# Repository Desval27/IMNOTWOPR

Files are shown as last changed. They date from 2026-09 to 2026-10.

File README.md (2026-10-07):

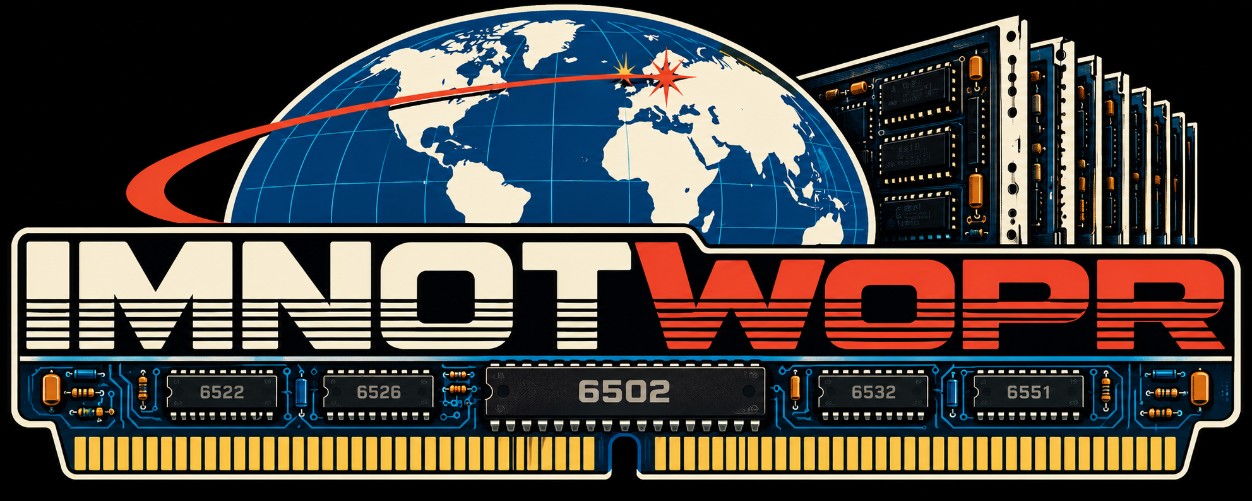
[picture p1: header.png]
Header


# IMNOTWOPR

**IMNOTWOPR** — *Information Management Network Operating Terminal & Wargames Optimized Planning Rig* — is a DIY-friendly, expandable 6502-family computer inspired by the architecture, modularity, and front-panel experience of classic systems such as the IMSAI 8080, while deliberately avoiding strict historical reproduction.

The system combines the open, card-oriented philosophy of S-100 machines with a **3U Eurocard mechanical format and 96-pin DIN 41612 backplane**. The result is intended to be a machine that is visually engaging, electrically accessible, mechanically robust, easy to modify, and suitable for experimenting with hardware, operating systems, peripherals, and alternative CPU configurations.

At its core, IMNOTWOPR is an attempt to build the kind of expandable 6502 computer that might have existed if the modular backplane philosophy of early microcomputers had evolved around the 6502 family instead of the Intel 8080.

## Project Goals

The primary goals of IMNOTWOPR are:

* Build a real, hardware-based 6502-family computer rather than an emulated system.
* Use a passive backplane and independent plug-in cards for CPU, memory, I/O, storage, video, sound, and other functions.
* Preserve the hands-on experience of classic front-panel computers, including blinking status lights, switches, processor control, and direct memory examination.
* Keep the architecture open and experimental rather than enforcing a single fixed memory map or peripheral layout.
* Favor through-hole and DIP components where practical.
* Use modern components where they provide clear benefits without hiding the operation of the machine.
* Make the system easy to probe, understand, modify, repair, and extend.
* Support both the W65C02 and eventual W65C816 CPU cards without redesigning the backplane.
* Provide room for experimenting with custom operating systems, monitors, device drivers, and unconventional hardware.

Historical authenticity is not a primary goal. The machine should feel like a classic expandable microcomputer while benefiting from several decades of hindsight.

## Current Status

All modules and panels are currently a work in progress and **NONE** have been tested yet.

- [Backplane](system/BACKPLANE/README.md)
- [PWR PCB](modules/PWR/README.md)
- [PWR Panel](panels/PWR/README.md)
- [Lightman serial terminal](lightman/README.md) - Pico RGB332 VGA/PS/2 serial terminal with VT100/VT52 firmware and on-device setup, including normal-text color selection.

## Mechanical Architecture

IMNOTWOPR uses the **3U Eurocard format**, with typical cards measuring approximately:

```text
160 mm × 100 mm
```

Cards plug into a passive backplane using **96-pin DIN 41612 connectors**.

This provides several advantages over a traditional PCB-edge S-100 connector:

* standardized card cages and guides,
* robust and replaceable connectors,
* good contact reliability,
* straightforward board insertion and removal,
* readily available mechanical hardware,
* flexible signal and ground assignment,
* and compatibility with existing Eurocard prototyping practices.

The Eurocard format also encourages functional separation. Rather than placing the entire system on one large PCB, the computer can evolve as a collection of specialized cards.

Typical cards may include:

```text
CPU
Memory
System Controller
Serial I/O
VIA / Parallel I/O
Mass Storage
Video
Sound
Networking
RTC
ADC / DAC
Front Panel
Prototype / Experimenter
```

The passive backplane itself should contain as little active circuitry as practical.

## System Bus

[Bus Allocation](doc/bus.md)

The IMNOTWOPR bus is inspired conceptually by S-100, but is designed specifically for the 6502 family.

The initial system is expected to use a **W65C02S**, while the backplane is provisioned from the beginning for eventual use with the **W65C816S**.

The bus therefore provides:

```text
A0-A23       24-bit address bus
D0-D7         8-bit bidirectional data bus

PHI2          System bus clock
R/W           Read/write direction
VALID         Valid external bus cycle
SYNC          Opcode-fetch indication

/RESET
/IRQ
/NMI
RDY

VPB
MLB

VDA
VPA
E
MX
/ABORT
```

Not every CPU implementation is required to generate every signal directly. CPU cards may synthesize bus-level signals so peripheral cards see a consistent interface.

For example, a W65C816 CPU card can latch the processor's multiplexed bank-address byte locally and present normal dedicated `A16-A23` signals to the backplane.

This means ordinary memory and peripheral cards do not need to understand the internal bus peculiarities of the installed processor.

## Address Space

The physical backplane provides a full:

```text
24-bit address bus
```

allowing up to:

```text
16 MiB
```

of physical address space.

A basic W65C02 CPU card operates naturally within bank `$00`:

```text
$000000-$00FFFF
```

with `A16-A23` normally held low.

Future CPU cards may use those lines differently. A W65C816 card can expose its complete 24-bit native address space, while an experimental W65C02 card could implement bank switching or other extended-address mechanisms.

The backplane does **not** enforce a fixed system memory map.

There is no mandatory division between RAM, ROM, and I/O, and no permanently assigned global I/O region. Individual cards may decode whichever portions of the address bus are appropriate.

This allows the machine to support very different system configurations without changing the backplane itself.

## Memory-Mapped I/O

IMNOTWOPR follows the native 6502 model of **memory-mapped I/O**.

Peripheral devices occupy normal addresses within the processor's address space rather than using a separate I/O instruction space.

The bus therefore does not require traditional S-100-style signals such as:

```text
IOR
IOW
INP
OUT
```

A peripheral card generally needs only:

```text
Address
Data
R/W
PHI2
VALID
```

plus any interrupt or DMA-related signals it requires.

This keeps peripheral design closely aligned with normal 6502 conventions.

## Power

Unlike classic S-100 systems, IMNOTWOPR does not distribute unregulated voltages and require every card to contain its own primary regulator.

The backplane distributes regulated power directly:

```text
+5 V      Main digital supply
+12 V     Auxiliary supply
-12 V     Auxiliary supply
GND       Common ground
```

The **+5 V rail** is the primary system supply and is used by normal CPU, memory, and logic cards.

The ±12 V rails are optional auxiliary services intended for devices such as:

* analog circuitry,
* audio interfaces,
* ADC/DAC hardware,
* legacy serial interfaces,
* storage devices,
* experimental peripherals,
* or other hardware requiring additional rails.

A normal digital card should not require ±12 V.

Multiple DIN 41612 contacts are assigned in parallel for +5 V and ground in order to reduce connector resistance and distribute current across the backplane.

Cards may include local filtering, bulk capacitance, protection, and optional secondary regulators as required.

Modern 3.3 V devices should normally derive their supply locally from +5 V rather than making 3.3 V a mandatory system-wide backplane rail.

## Front Panel

A dedicated front-panel controller provides one of the defining features of IMNOTWOPR: a large, interactive display inspired by machines such as the IMSAI 8080.

The panel may include indicators for:

```text
A0-A23
D0-D7
R/W
PHI2
SYNC
IRQ
NMI
RESET
BUS STATE
```

along with physical toggle or push-button controls.

Planned operator functions include:

```text
RUN
STOP
SINGLE CYCLE
SINGLE INSTRUCTION
RESET
EXAMINE
EXAMINE NEXT
DEPOSIT
DEPOSIT NEXT
```

The front panel is not intended merely as decoration. It participates directly in system operation.

### Processor Control

The panel can request that the CPU halt through dedicated control signals.

A processor card handles the details of stopping its particular CPU safely and returns an acknowledgement when it has reached a stable halted state.

This keeps CPU-specific control logic on the CPU card rather than embedding assumptions about a specific processor into the front panel.

### Bus Arbitration

For functions such as `EXAMINE` and `DEPOSIT`, the front-panel controller can temporarily request ownership of the system bus.

The basic handshake is:

```text
/BUS_REQ
/BUS_ACK
```

Once ownership is granted, the CPU card removes its address, data, and control drivers from the bus.

The front-panel controller then becomes a temporary bus master and can perform memory reads and writes directly.

This allows classic front-panel operation without relying on the processor to execute monitor code.

## Clocking

`PHI2` is treated as a **system bus clock**, not merely a private CPU pin.

Halting the processor does not necessarily halt the system clock.

This makes it possible for the front panel and other bus masters to perform valid bus cycles while the processor is stopped.

The initial CPU card may provide the master clock source, although a future dedicated system-controller card could assume that responsibility.

Clock speed is intentionally not fixed by the backplane specification.

The system should be able to operate slowly enough for observation and experimentation while remaining capable of significantly higher speeds when appropriately designed cards are installed.

## Bus Arbitration and Expansion

IMNOTWOPR is designed with the possibility of multiple bus masters.

Potential bus masters may eventually include:

* the CPU,
* front-panel controller,
* DMA controller,
* video hardware,
* storage controller,
* diagnostic hardware,
* or other experimental cards.

A generic request/acknowledge mechanism is preferred over exposing CPU-specific signals directly.

For example:

```text
/BUS_REQ
/BUS_ACK
```

allows a CPU card to translate the generic bus request into whatever mechanism its particular processor requires.

This makes the backplane less dependent upon the details of the W65C02 or W65C816.

## 65C02 and 65C816 Compatibility

The first CPU implementation is expected to use the **W65C02S**.

For that configuration:

```text
A0-A15   CPU address
A16-A23  normally 0
D0-D7    CPU data
```

The backplane nevertheless carries all 24 address bits.

A future **W65C816S** CPU card can use:

```text
A0-A23
D0-D7
```

as a native 24-bit address / 8-bit data architecture.

Any multiplexing required by the processor is handled locally on the CPU card.

The intent is that most RAM, ROM, I/O, and peripheral cards designed for IMNOTWOPR should work with either CPU without modification.

## Component Philosophy

IMNOTWOPR intentionally favors components that remain approachable to hobbyists.

Preferred technologies include:

* W65C02S and W65C816S processors,
* 74HC / 74HCT-series logic,
* DIP SRAM,
* EEPROM or Flash devices,
* W65C22 VIA,
* UARTs and similar peripheral ICs,
* discrete transistors,
* socketed programmable logic where useful,
* and through-hole connectors and passive components.

Surface-mount components are not prohibited, but should not be required merely for convenience if a practical through-hole alternative exists.

Programmable logic such as GALs, CPLDs, or microcontrollers may be used where appropriate, but the core operation of the system should remain understandable without treating large programmable devices as black boxes.

## Open Architecture

One of the fundamental goals of IMNOTWOPR is to avoid defining unnecessary policy at the backplane level.

The system therefore does not require:

* a specific ROM monitor,
* a particular operating system,
* fixed RAM size,
* fixed peripheral addresses,
* a specific storage format,
* a mandatory video system,
* or a single standard machine configuration.

A minimal system might consist of:

```text
CPU
RAM
ROM
Serial I/O
```

while a larger system could contain:

```text
CPU
Multiple RAM cards
ROM / Flash
Serial interfaces
Parallel interfaces
Mass storage
Video
Audio
Networking
Front panel
RTC
ADC / DAC
Custom hardware
```

Both configurations are equally valid.

## Software

Software development is expected to be just as experimental as the hardware.

Possible software projects include:

* machine-language monitors,
* assemblers,
* BASIC interpreters,
* Forth systems,
* custom operating systems,
* multitasking experiments,
* filesystem development,
* device-driver frameworks,
* bootloaders,
* networking stacks,
* 65C816 native-mode software,
* and compatibility environments for existing 6502 software.

No particular software environment is considered canonical.

The machine should be capable of evolving alongside the software written for it.

## Initial Planned Cards

The first generation of the system will likely include some subset of the following:

### CPU Card

W65C02-based processor card providing:

* processor,
* clock generation,
* address and data buffering,
* interrupt handling,
* bus arbitration,
* halt/step support,
* and 24-bit bus adaptation.

### Memory Card

Configurable RAM and ROM/Flash with selectable address decoding.

### Serial Card

Basic terminal interface suitable for initial software development and debugging.

### Front-Panel Controller

Controls system operation and provides address/data/status indicators, processor control, and Examine/Deposit functionality.

### VIA / General I/O Card

One or more W65C22 devices providing:

* digital I/O,
* timers,
* handshake lines,
* interrupts,
* and general experimentation facilities.

### Prototype Card

A general-purpose experimenter board exposing the system bus and providing space for custom circuitry.

Future cards may include storage, video, audio, networking, RTC, ADC/DAC, and other experimental hardware.

## Design Philosophy

IMNOTWOPR is not intended to be the smallest, fastest, cheapest, or most integrated 6502 computer possible.

There are already much easier ways to build those.

Instead, the project deliberately values:

```text
Visibility
Modularity
Experimentation
Repairability
Understandability
Physical controls
Blinking lights
Too many circuit boards
```

over integration.

The machine should invite its owner to remove cards, attach probes, change memory maps, build strange peripherals, write questionable operating systems, single-step instructions from the front panel, and occasionally wonder why there are quite so many LEDs.

That is the point.

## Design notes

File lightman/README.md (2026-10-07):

# lightman

Lightman is a Raspberry Pi Pico (RP2040) serial terminal with RGB332 VGA output,
PS/2 keyboard input, and a DTE male DE-9 RS-232 port through MAX3232 transceivers.

The firmware baseline provides 80x24 text, common VT100/VT52 controls, a US
keyboard layout, buffered UART I/O, an on-device setup menu, and two embedded
fonts. It builds to a Pico UF2. Host tests and cross-compilation are verified;
physical VGA/PS/2/serial operation still needs prototype validation. See the
[compatibility matrix](docs/compatibility.md) for implemented sequences and gaps.

## Build and flash

Dependencies: CMake 3.24+, Python 3, an Arm GNU embedded C/C++ compiler with
C++23 support, and the official Pico SDK (tested: SDK 2.2.0 and GCC 13.2.1).
The SDK builds/downloads `pioasm` and `picotool` if needed. Initialize SDK
submodules for a complete SDK checkout; USB is not used by this firmware.

From the repository root:

```sh
git clone --branch 2.2.0 --depth 1 https://github.com/raspberrypi/pico-sdk.git /path/to/pico-sdk
git -C /path/to/pico-sdk submodule update --init
cmake -S lightman/firmware -B lightman/build/pico \
  -DPICO_SDK_PATH=/path/to/pico-sdk -DCMAKE_BUILD_TYPE=Release
cmake --build lightman/build/pico -j
```

Hold BOOTSEL while connecting the Pico over USB, then copy
`lightman/build/pico/lightman.uf2` to the `RPI-RP2` drive. BOOTSEL flashing works
independently of USB support in the application. UART/USB debug stdio are
both disabled so debug text cannot pollute the serial terminal connection.
The board/layout target is the original 2 MiB Pico, not Pico 2 or Pico W.

## Wiring

| Function | GPIO |
| --- | --- |
| UART TX / RX | 0 / 1 |
| CTS / RTS | 2 / 3 |
| DTR / DSR | 5 / 4 |
| DCD / RI | 6 / 7 |
| PS/2 clock / data | 8 / 9 |
| VGA HSYNC / VSYNC | 13 / 14 |
| VGA R0 / R1 / R2 | 15 / 16 / 17 |
| VGA G0 / G1 / G2 | 18 / 19 / 20 |
| VGA B0 / B1 | 21 / 22 |

See [wiring and electrical interfaces](docs/wiring.md) before connecting the
board. Three MAX3232s support all eight DE-9 signals: TX/RX, RTS/CTS, DTR/DSR,
and DCD/RI, with common ground on pin 5. DSR, DCD and RI are status inputs
displayed in setup; they do not gate serial traffic.
The VGA resistor DACs use channel 0 as the most significant bit; see the wiring
guide for resistor values and signal order.

## Setup

Defaults are **9600 baud, 8N1, no flow control, VT100, local echo off, DEL
Backspace, Regular font, amber normal text**. Press **F12** to open setup.

- Up/Down selects a setting; Left/Right or Space changes it.
- Enter applies settings for this session.
- S applies and saves settings to flash.
- Esc or F12 cancels the draft changes.
- The last menu row restores factory defaults to the draft; apply/save it
  using Enter/S. Terminal mode changes clear the terminal screen.

Choose 300–115200 baud, 7/8 data bits, parity, stop bits, flow control, terminal
mode, echo, Backspace behavior, Regular/Bold font, and **Normal color**:
White, Classic green, Yellow, Amber, Red, Blue, Cyan or Magenta. Color changes
preview immediately in setup; Enter applies, S saves, and Esc/F12 restores the
previous color. Normal color is the base foreground on black; bold, underline,
blink, reverse video and the cursor use the same color. ANSI color SGR remains
unsupported. Amber uses RGB332 levels R=7, G=4, B=0.
The menu shows UART errors, dropped TX/PS/2 data, missed VGA deadlines, and
live DSR, DCD and RI status.
Incoming host text continues updating a separate terminal screen during setup.

Pause the host before changing serial framing or saving. Flash saves briefly
blank VGA and suspend interrupt handling. Two checksummed flash records protect
against an interrupted save; normal UF2 updates preserve saved settings.
Existing saved White/Green/Yellow choices remain valid. Amber is the default
when no valid settings exist or when factory defaults are restored.

## Fonts

Both fonts are compiled into firmware and selected at runtime. Developers can
replace the build-time inputs using `LIGHTMAN_REGULAR_FONT` and
`LIGHTMAN_BOLD_FONT`. See [font assets, format and licensing](assets/fonts/README.md).

## Tests

Portable tests do not require the Pico SDK:

```sh
cmake -S lightman/firmware -B lightman/build/host \
  -DLIGHTMAN_HOST_TESTS=ON -DCMAKE_BUILD_TYPE=Debug
cmake --build lightman/build/host -j
ctest --test-dir lightman/build/host --output-on-failure
```

Tests cover terminal positioning/scrolling/modes/replies, malformed streams,
keyboard sequences, PS/2 frame parity and timeout, settings validation/CRC,
all normal-color presets and their persistence, RGB332 DAC bit mapping,
and generated font data. A seeded 250,000-byte malformed-input exercise checks
cursor bounds. For sanitizer checks add
`-DCMAKE_CXX_FLAGS="-fsanitize=address,undefined -fno-omit-frame-pointer"` to a
separate host build directory. See [hardware acceptance checks](tests/bringup.md)
for the remaining bench work.

## Layout and architecture

- `firmware/src/terminal.cpp`, `keyboard.cpp`, `config.cpp`: portable core.
- `firmware/src/video.cpp`, `video.pio`: PIO/DMA VGA on core 1; core 0 renders
  packed glyph rasters into three buffers and publishes completed frames.
  `firmware/include/colors.h` defines the normal-color palette and DAC encoding.
- `firmware/src/serial.cpp`, `ps2.cpp`: interrupt-driven input; bounded queues.
- `firmware/src/main.cpp`, `settings.cpp`: local setup and flash persistence.
- `firmware/boards/`: pin map; `assets/fonts/`: source fonts and license.
- `tests/`: portable tests and bench procedures; `tools/`: font converter.
- `hardware/`, `mechanical/`: carrier-board and enclosure designs.

Original source is under the repository [MIT license](../LICENSE). Embedded
font assets have their own SIL Open Font License. Dependencies are the official
[Pico SDK](https://github.com/raspberrypi/pico-sdk) and its build tools.

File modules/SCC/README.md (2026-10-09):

# SCC PCB

System Control Card PCB

Status: ⚠Untested⚠

The SCC module provides power control, status indication, and manual bus reset for the IMNOTWOPR computer. It switches the ATX power supply through the backplane power-on signal and uses separate LEDs to indicate standby power and PSU power-good status, automatically extinguishing the standby LED when main power is enabled. The board also provides connections for monitoring the +5 V, +12 V, −12 V, and +12 V2 rails with voltage meters.

Additional info forthcoming.

The SCC module replaces the prior SCC module and corrects some of its defects.

## Documents

- [Schematic](SCC_schematic.pdf)
- [Assembly](SCC_assembly.pdf)
- [Bill of Materials](bom.csv)
- [Interactive Bill of Materials](ibom.html)

## Gerber To Order

- [Default](gerber_to_order/SCC_160.0x100.0mm_for_Default.zip)
- [Elecrow](gerber_to_order/SCC_160.0x100.0mm_for_Elecrow.zip)
- [FusionPCB](gerber_to_order/SCC_160.0x100.0mm_for_FusionPCB.zip)
- [JLCPCB](gerber_to_order/SCC_160.0x100.0mm_for_JLCPCB.zip)
- [PCBWay](gerber_to_order/SCC_160.0x100.0mm_for_PCBWay.zip)

## Rendered Images

### Top 3D

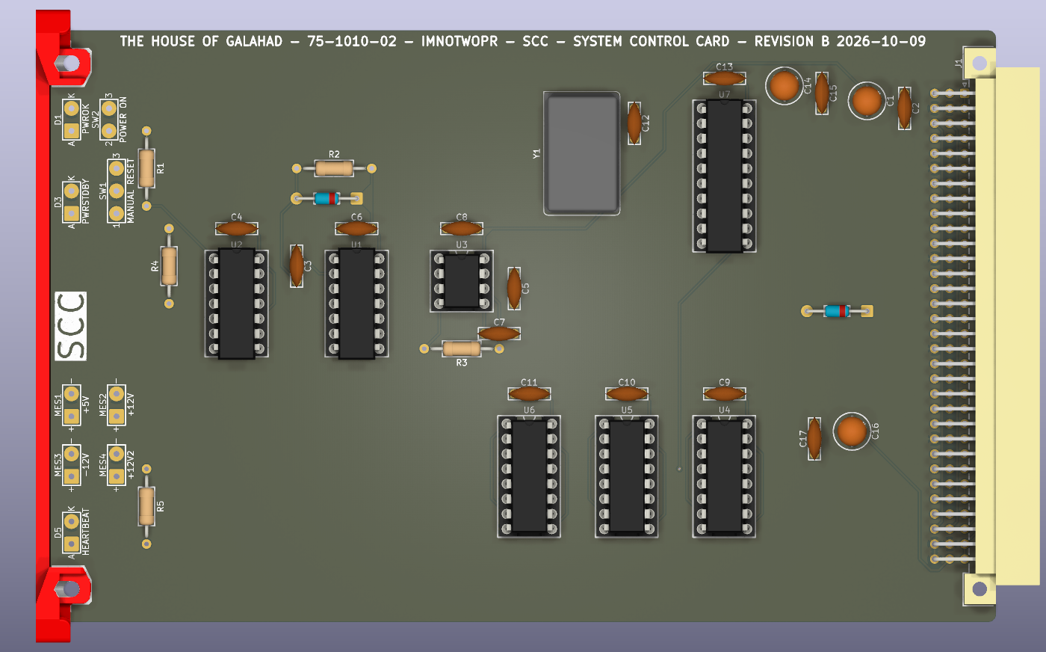
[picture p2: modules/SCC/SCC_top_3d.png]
PCB Top 3D Render


### Top

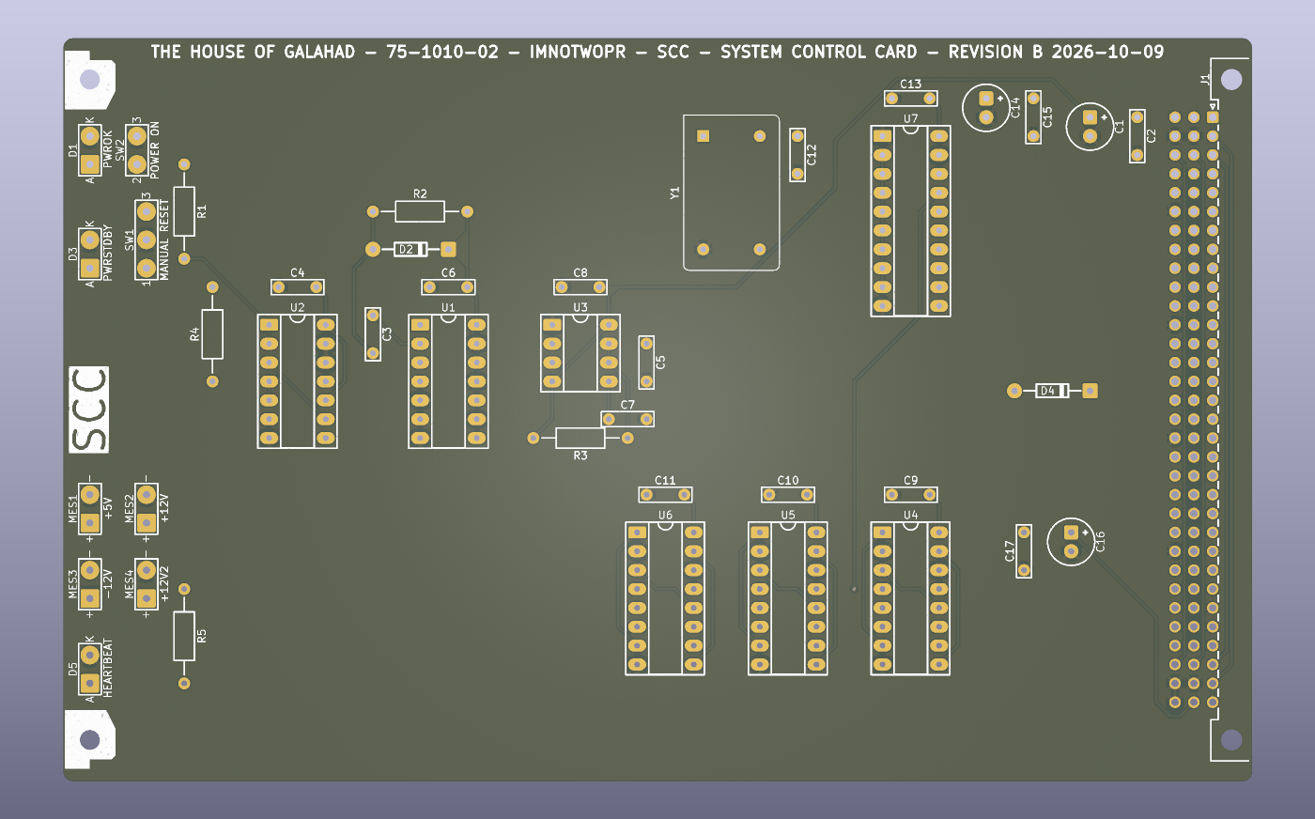
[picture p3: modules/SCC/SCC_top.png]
PCB Top Render


### Bottom

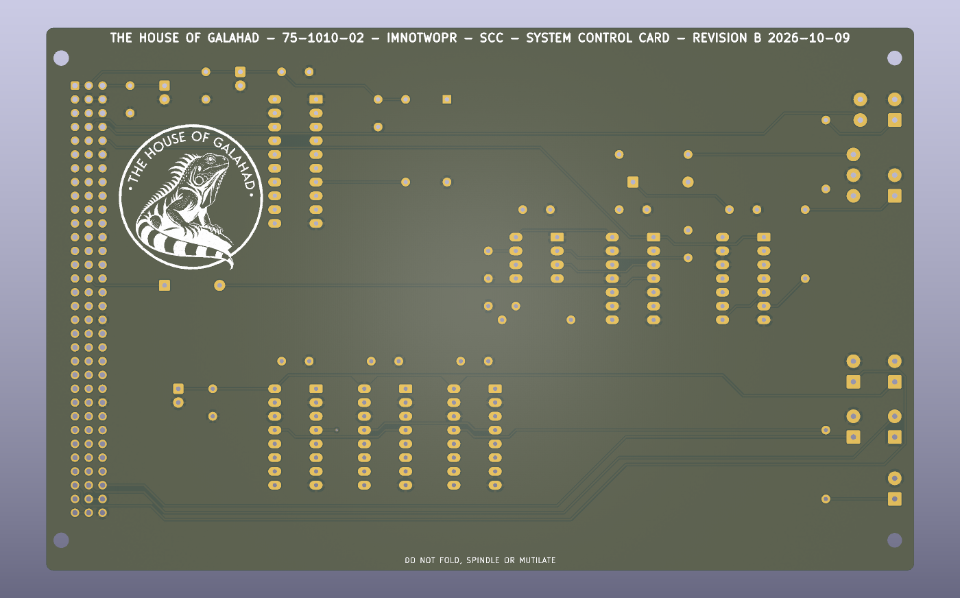
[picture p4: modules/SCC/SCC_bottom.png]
PCB Bottom Render


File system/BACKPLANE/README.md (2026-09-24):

# BACKPLANE

System Bus

Status: Untested

The BACKPLANE PCB provides the shared bus and power distribution for the IMNOTWOPR modular computer, connecting CPU, memory, I/O, and front-panel cards through 20 96-pin DIN 41612 slots. It carries the 24-bit address bus, 8-bit data bus, clock and control signals, and auxiliary I²C and SPI interfaces. ATX power connectors supply the system power rails, with standby power and power-control signals available to the cards. The passive design also includes jumper-selectable I²C pull-ups.

The PWR module and the BACKPLANE both provide the option for I²C pull-ups for convenience.  Only on should be enabled at a time.

## Documents

- [Schematic](BACKPLANE_schematic.pdf)
- [Assembly](BACKPLANE_assembly.pdf)
- [Bill of Materials](bom.csv)
- [Interactive Bill of Materials](ibom.html)

## Gerber To Order

- [Default](gerber_to_order/BACKPLANE_425.28x128.7mm_for_Default.zip)
- [Elecrow](gerber_to_order/BACKPLANE_425.28x128.7mm_for_Elecrow.zip)
- [FusionPCB](gerber_to_order/BACKPLANE_425.28x128.7mm_for_FusionPCB.zip)
- [JLCPCB](gerber_to_order/BACKPLANE_425.28x128.7mm_for_JLCPCB.zip)
- [PCBWay](gerber_to_order/BACKPLANE_425.28x128.7mm_for_PCBWay.zip)

## Rendered Images

### Top 3D

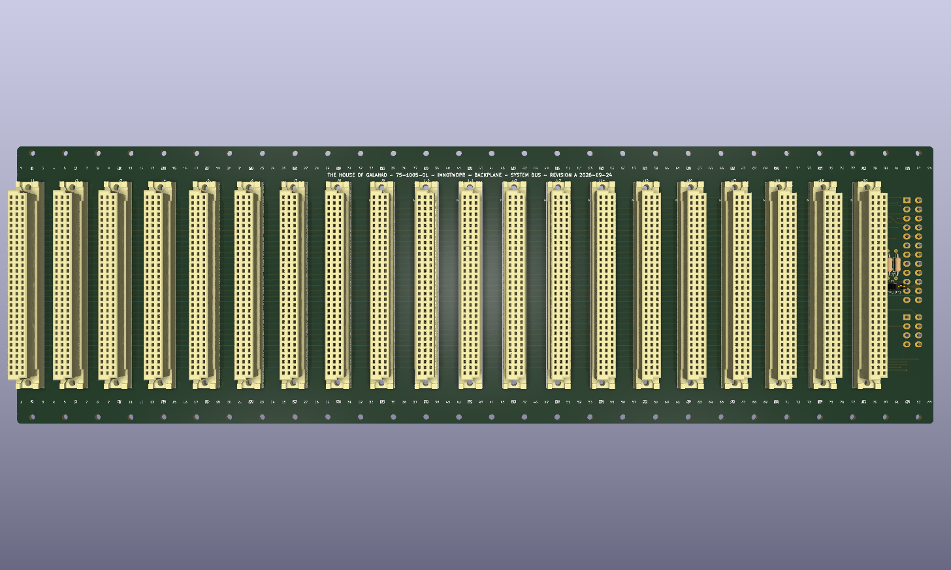
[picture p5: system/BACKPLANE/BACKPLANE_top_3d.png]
PCB Top 3D Render
 3D

### Top

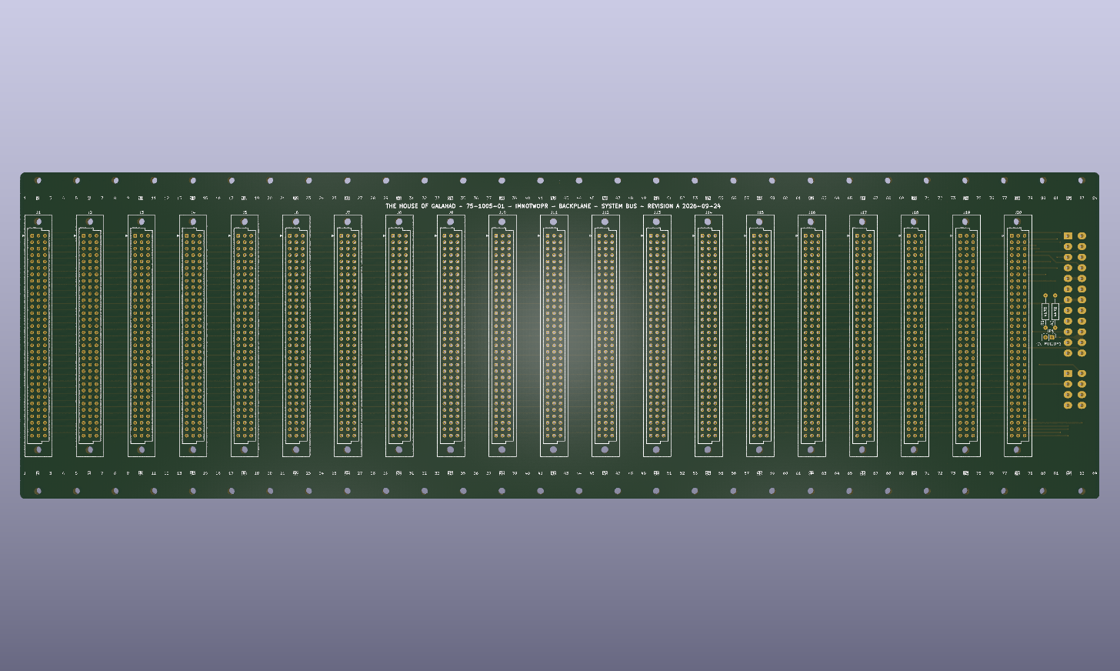
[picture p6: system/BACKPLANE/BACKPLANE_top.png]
PCB Top Render


### Bottom

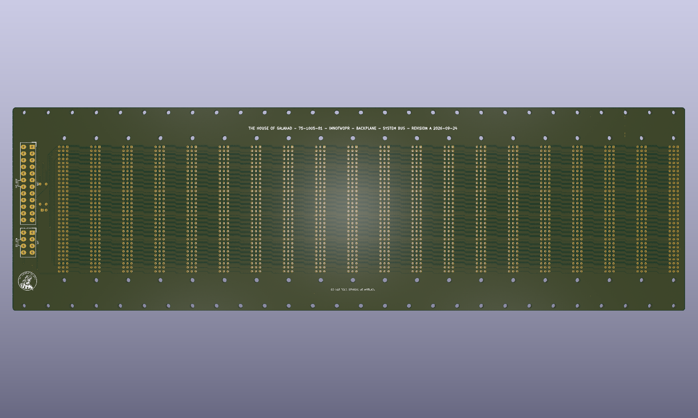
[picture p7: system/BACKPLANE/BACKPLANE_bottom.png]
PCB Bottom Render


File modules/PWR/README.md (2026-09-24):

# PWR PCB

Power Control Module PCB

Status: Untested

The PWR module provides power control, status indication, and manual bus reset for the IMNOTWOPR computer. It switches the ATX power supply through the backplane power-on signal and uses separate LEDs to indicate standby power and PSU power-good status, automatically extinguishing the standby LED when main power is enabled. The board also provides connections for monitoring the +5 V, +12 V, −12 V, and +12 V2 rails with voltage meters, along with jumper-selectable I²C pull-ups.

The PWR module and the BACKPLANE both provide the option for I²C pull-ups for convenience.  Only on should be enabled at a time.

## Documents

- [Schematic](PWR_schematic.pdf)
- [Assembly](PWR_assembly.pdf)
- [Bill of Materials](bom.csv)
- [Interactive Bill of Materials](ibom.html)

## Gerber To Order

- [Default](gerber_to_order/PWR_160.0x100.0mm_for_Default.zip)
- [Elecrow](gerber_to_order/PWR_160.0x100.0mm_for_Elecrow.zip)
- [FusionPCB](gerber_to_order/PWR_160.0x100.0mm_for_FusionPCB.zip)
- [JLCPCB](gerber_to_order/PWR_160.0x100.0mm_for_JLCPCB.zip)
- [PCBWay](gerber_to_order/PWR_160.0x100.0mm_for_PCBWay.zip)

## Rendered Images

### Top 3D

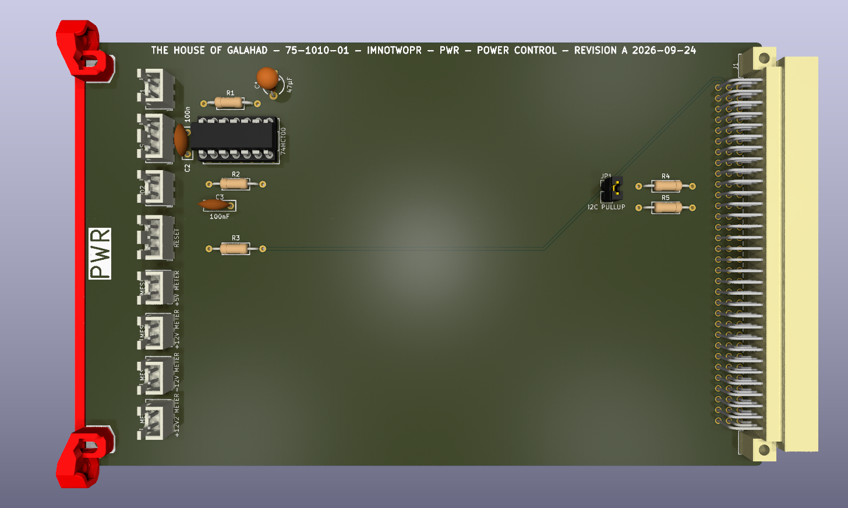
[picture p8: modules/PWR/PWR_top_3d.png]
PCB Top 3D Render


### Top

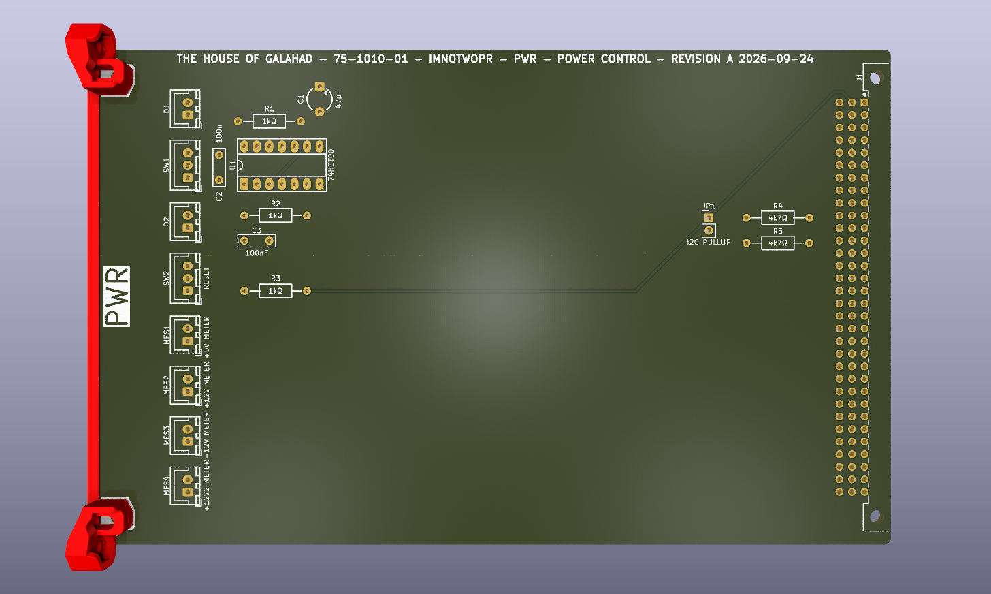
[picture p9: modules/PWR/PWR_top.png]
PCB Top Render


### Bottom

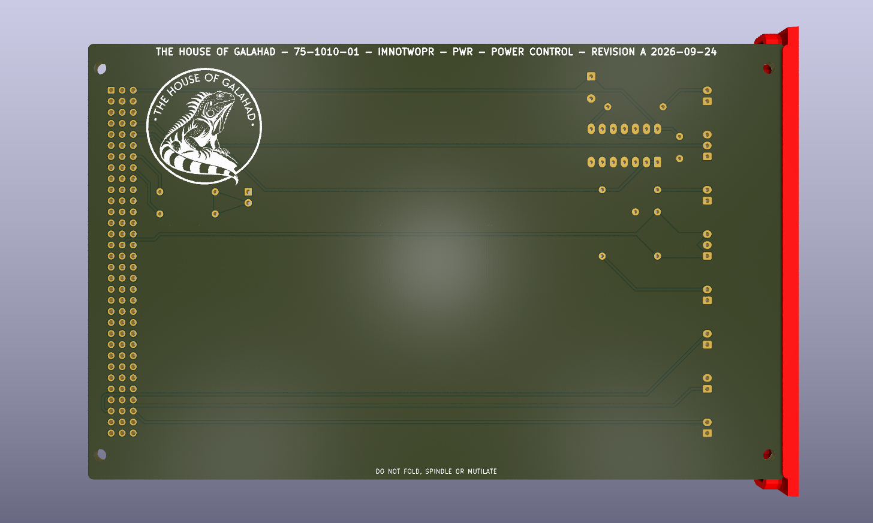
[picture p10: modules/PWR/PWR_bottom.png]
PCB Bottom Render


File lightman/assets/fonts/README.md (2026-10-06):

# Embedded fonts

`lightman-regular.psf` and `lightman-bold.psf` are 8x16 Unicode-mapped PSF inputs
obtained from Debian/Ubuntu `console-setup-linux`'s `Lat15-Terminus16.psf.gz`
and `Lat15-TerminusBold16.psf.gz`. They derive from **Terminus Font**, copyright
(c) 2010 Dimitar Toshkov Zhekov. See [OFL.txt](OFL.txt) for the complete SIL Open
Font License 1.1 and reserved-name notice. Lightman's converted/embedded
derivatives are named Lightman Regular and Lightman Bold.

The build embeds ASCII 32–126, with blank control characters. Firmware supplies
DEC drawing glyphs separately. Font rows use the high bit as the left pixel.
These font assets remain under the OFL; the rest of Lightman's original source
uses the repository MIT license.

The fixed runtime set consists of Regular and Bold. Setup selects the base
font; SGR bold always chooses the Bold slot. Developers can replace either at
build time:

```sh
cmake -S lightman/firmware -B lightman/build/pico \
  -DPICO_SDK_PATH=/path/to/pico-sdk \
  -DLIGHTMAN_REGULAR_FONT=/absolute/path/regular.psf \
  -DLIGHTMAN_BOLD_FONT=/absolute/path/bold.psf
cmake --build lightman/build/pico -j
```

Inputs must be uncompressed PSF1 or PSF2, 8x16, with a Unicode mapping covering
printable ASCII. The converter rejects incompatible or truncated files. Font
changes automatically regenerate `fonts.h`; Python is a build dependency only.
Preserve the license/attribution of any replacement fonts. Font dimensions and
slot count are fixed in this baseline; adding different cell sizes requires
corresponding renderer, layout, configuration and tests changes.

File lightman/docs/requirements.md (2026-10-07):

# Lightman baseline requirements

The initial firmware targets the original Raspberry Pi Pico (RP2040, 2 MiB
flash). See [platform](platform.md), [wiring](wiring.md), and
[compatibility](compatibility.md) for implementation details.

| Area | Selected baseline |
| --- | --- |
| Display | Fixed 640x480 at 60 Hz; 80x24 text centered vertically |
| VGA pins | HSYNC 13, VSYNC 14, R0..R2 15..17, G0..G2 18..20, B0..B1 21..22 |
| Color | RGB332 resistor DACs; channel 0 is most significant; amber normal text by default |
| Keyboard | PS/2 set 2 through level shifters; US layout; clock GPIO8, data GPIO9 |
| Serial | UART0 on GPIO0/1; three MAX3232s support all DTE male DE-9 signals |
| Optional handshaking | CTS/RTS on GPIO2/3, DTR/DSR on GPIO5/4 |
| Modem status | DSR on GPIO4, DCD on GPIO6, RI on GPIO7; live status in setup |
| Framing | 300–115200 baud, 7/8 bits, N/E/O parity, 1/2 stop bits |
| Flow | None, XON/XOFF or RTS/CTS; bounded RX/TX queues |
| Emulation | Documented VT100/VT52 subset, ASCII and DEC drawing characters |
| Setup | F12 local menu, session apply or persistent save; eight normal-color presets including Classic green, Amber and White |
| Fonts | Fixed Regular/Bold set; developer-replaceable 8x16 PSF inputs |
| Persistence | Two versioned CRC32 records in the last two flash sectors |
| Build | C++23, CMake, Pico C SDK; portable host tests |

US layout and DTE wiring were confirmed for this baseline. USB keyboard input,
modem management, and complete DEC conformance remain outside the current
implementation. Power, enclosure, connector footprints and PCB routing still
require hardware validation against the updated pin map.

Before declaring hardware support validated, complete the
[bring-up procedure](../tests/bringup.md), including VGA deadline monitoring
under sustained serial/keyboard load and settings-save recovery.

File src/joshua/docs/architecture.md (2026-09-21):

# Architecture and initial specification

Joshua is the hosted development companion to IMNOTWOPR. The hardware repository
intentionally does not define a mandatory memory map; Joshua follows that rule.
The initial processor has a 16-bit address space. Future 65816/banked systems are
not implied by the first implementation.

## Ownership

```mermaid
flowchart TD
    App[Console application] --> Monitor
    App --> Machine
    Monitor --> Machine
    Machine --> CPU[W65C02 CPU]
    Machine --> Bus[Memory map and bus clock]
    CPU --> Bus
    Bus --> RAM
    Bus --> ROM
    Bus --> VIA[W65C22 VIA]
    Bus --> ACIA[W65C51N ACIA]
    App --> Terminal[POSIX or Windows terminal]
    Terminal --> ACIA
```

`Machine` composes the CPU, bus, device instances and execution breakpoints. The
CPU depends only on `Bus`, not the console, monitor, profile format or a particular
memory map. `Device` defines read, write, peek, reset, tick and IRQ behavior. A
RAM/ROM device is storage with a protection policy. The bus decoder has no built-in
IMNOTWOPR addresses. Mappings are immutable after machine construction in 0.1.

The public headers are under `include/joshua`; implementation is under `lib`.
`app/terminal.cpp` contains the platform-specific APIs. The core uses standard
C++23 and can be embedded in a different host application without console code.
No network service, compiler, external assembler or third-party CPU library runs
inside Joshua.

## Execution and time

`Cpu::step()` completes one instruction or interrupt entry. Each CPU read/write
calls the bus; the bus performs the access, advances one cycle, ticks every mapped
device, and optionally emits a `BusCycle` record. Dummy reads are real bus reads,
including their device side effects. Read-modify-write instructions use the CMOS
two-read/one-write sequence. Device time is never advanced in a lump after an
instruction.

Bus time is a monotonically increasing 64-bit cycle count. Reset takes seven bus
cycles and retains the elapsed counter. Power-on gives deterministic initial
register values; software must still initialize registers as it would on hardware.
Reset adjusts SP by three, sets I and clears D, and loads the reset vector.

The public stepping boundary is an instruction, not an individual PHI2 edge.
WAI advances peripherals while the CPU is waiting; STP stops CPU execution until
reset. IRQ is the logical OR of the mapped devices' IRQ state; NMI is explicitly
latched. The current interrupt decision is made at instruction boundaries.
This does not yet reproduce all interrupt sampling windows or external pin edges.

The host run loop handles terminal input, drains completed serial bytes, evaluates
execution breakpoints and optionally paces execution against `steady_clock`.
Host sleeps do not advance emulated time. Input is polled in bounded batches so a
large paste cannot starve execution. There is no background emulation thread;
paused inspection does not race CPU execution.

## Debugger semantics

`Bus::peek()` is a side-effect-free device view. `Bus::patch()` validates all
addresses before modifying RAM/ROM and does not tick devices. The monitor's load,
deposit and assembler use this path; save and disassembly use peek. Explicit
`io` commands use the normal read/write path. No implicit device write happens
when opening a memory view.

Instruction decoding, disassembly and ad-hoc assembly share one opcode table.
Breakpoints are host metadata, never BRK patches in the guest image. There are no
symbol files, read/write watchpoints, conditional breakpoints or snapshot files in
0.1; raw binary load/save operates only on memory bytes.

## Configuration decisions

- Initial machine: W65C02, VIA at `$8000`, ACIA at `$8010`, 32 KiB RAM and 16 KiB ROM.
- W65C51 means the current W65C51N behavior, including its transmit-empty quirk.
- CPU clock: 1 MHz by default. ACIA reference: 1.8432 MHz; default asserted DCD,
  DSR and CTS inputs represent a connected terminal.
- Input control: Ctrl-] enters the monitor. `run` resumes. The profile/CLI can
  change the escape byte; `send` can inject that byte into the guest.
- Config files use a strict, small `key = value` grammar and no dependency on
  TOML/JSON libraries. Unknown options and invalid maps fail before execution.
- Default number notation is monitor-style hexadecimal. Base prefixes are explicit.
- Unmapped reads return `$FF`; unmapped and ROM CPU writes are ignored.
- Map aliases, overlapping decode/bank switching and multiple VIA/ACIA instances
  are future extensions. Multiple distinct RAM and ROM regions already work.

## Next accuracy work

The immediate hardware work is to validate peripheral timing and interrupt entry
against captures from the actual IMNOTWOPR parts. VIA shift modes, port latching,
and CA/CB handshakes need a pin model. UART echo, break and modem-line transitions
need an explicit serial-line model. Unsupported configuration modes currently
raise an error so they cannot silently appear to work.

After that, introduce externally driven RDY/reset/NMI/IRQ lines and a resumable
single-cycle CPU interface for front-panel or bus-arbitration work. Keep these
changes below `Machine`; neither the monitor nor terminal should determine
processor timing.

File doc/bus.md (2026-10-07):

# IMNOTWOPR BUS ASSIGNMENT #

The system bus uses a **96-pin DIN 41612 connector** which is broken out into three different rows.

| PIN  | a | b | c |
| :----: | :---: | :---: | :---: |
| 1 | +5V | +5V | +5VSB |
| 2 | +5V | GND | GND |
| 3 | +12V | -12V | +12V2 |
| 4 | A0 | #VALID | #PSON |
| 5 | A1 | PHI2 | PWROK |
| 6 | A2 | #RW | GND |
| 7 | A3 | #RESET | I2C_SCL  |
| 8 | A4 | #IRQ | I2C_SDA  |
| 9 | A5 | #NMI | SPI_SCK  |
| 10 | A6 | READY | SPI_MOSI |
| 11 | A7 | BE | SPI_MISO |
| 12 | A8 | SYNC | GND |
| 13 | A9 | VPB | SPI_ID0  |
| 14 | A10 | MLB | SPI_ID1  |
| 15 | A11 | VDA | SPI_ID2  | 
| 16 | A12 | VPA | SPI_ID3  |
| 17 | A13 | E | #SPI_SEL |
| 18 | A14 | MX | GND |
| 19 | A15 | RESERVED  | #SERIRQ  |
| 20 | A16 | RESERVED  | #BUSREQ0 |
| 21 | A17 | RESERVED  | #BUSGNT0 |
| 22 | A18 | D0 | #BUSREQ1 |
| 23 | A19 | D1 | #BUSGNT1 |
| 24 | A20 | D2 | GND |
| 25 | A21 | D3 | #BUSREQ2 |
| 26 | A22 | D4 | #BUSGNT2 |
| 27 | A23 | D5 | #BUSREQ3 |
| 28 | RESERVED | D6 | #BUSGNT3 |
| 29 | RESERVED | D7 | RESERVED |
| 30 | +12V | -12V | +12V2 |
| 31 | +5V | GND | GND |
| 32 | +5V | +5V | GND |

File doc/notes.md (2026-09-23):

# Mechanical Design Notes

These notes define the revised PCB, front-panel, and backplane specifications, using 4 HP (20.32 mm) card spacing. The KiCad layouts are pending updates to match this specification; see [Layout Updates Pending](#layout-updates-pending).

## PCB and Front-Panel Specifications

The mechanical design uses a simplified interpretation of IEC 60297-3-101. The original reference is this [system explanation](https://www.scribd.com/document/53335543/IEC-60297-3-101-system-explanation), rather than the standard itself. The closest configuration is an unshielded plug-in unit with static cantilever handles. Handle mounting holes are omitted for appearance but can be added if needed.

- **Card cage:** SCHROFF [24564-131](https://www.nvent.com/en-us/schroff/products/enc24564-131), a 3U, 84 HP, 175 mm-deep subrack for 160 mm cards, with rear L-ST rails, threaded inserts, and insulation strips.
- **Card size:** Single-height Eurocards, 160 mm deep by 100 mm high, for use in a 3U subrack.
- **PCB thickness:** 1.6 mm.
- **PCB brackets:** nVent SCHROFF [60807-011](https://www.nvent.com/en-us/schroff/products/enc60807-011) brackets attach the PCBs to the front panels using M2.5 hardware. Other brackets may work but have not been tested for this project.
- **Front-panel height:** 128.4 mm, sized for a 3U subrack.
- **Front-panel width:** The intended design uses multiples of 4 HP, where 1 HP = 5.08 mm (0.200 in). Physical panels are slightly narrower than their nominal HP allocation to provide clearance.

Typical panel widths are listed below. The physical widths match the [SCHROFF front-panel catalog](https://www.nvent.com/sites/default/files/acquiadam_assets/2023-04/7_1_schroff_cat_frontpanels_en.pdf).

| Nominal width | Allocated width | Physical panel width |
| --- | --- | --- |
| 4 HP | 20.32 mm | 20.0 mm |
| 8 HP | 40.64 mm | 40.3 mm |
| 12 HP | 60.96 mm | 60.6 mm |
| 16 HP | 81.28 mm | 80.9 mm |

Other panel widths are possible, provided they accommodate the card spacing and components. To fill an 84 HP subrack, the nominal widths of all panels, including any blanking panels, must total 84 HP.

### Bracket Mounting Holes

- **On the front panel:** Both hole centers lie 7.45 mm from the left edge, viewed from the front. The lower hole is 14.7 mm above the bottom edge. The upper hole is 99 mm above the lower hole, placing it 14.7 mm below the top edge.
- **On the PCB:** The intended hole diameter is 2.7 mm for M2.5 hardware. Both centers are specified as 3.56 mm from the front edge of the card (the left edge in the PCB template). The holes are 88.9 mm apart vertically and centered within the board's 100 mm height, leaving 5.55 mm from each hole center to the nearest top or bottom edge.

## Backplane Specifications

The backplane spans 84 HP and provides 21 connector positions at 4 HP (20.32 mm) spacing. Reserving the rightmost 4 HP position for power management leaves 20 positions for other cards. Wider cards may occupy more than one position.

The dimensions below define the revised backplane geometry, viewed from the connector side. Horizontal connector locations use the first slot pitch reference plane, not the cut PCB edge. Vertical offsets use the bottom PCB edge. Hole locations refer to their centers.

### Board Outline and Mounting Holes

| Feature | Revised dimension or location |
| --- | --- |
| Nominal 84 HP allocation | 426.72 mm (16.800 in); not the physical PCB width |
| Physical board width | 425.28 mm design target, centered on the 84 HP mounting grid |
| Board height | 128.70 mm (5.067 in) |
| Bottom mounting-hole row | 3.10 mm above the bottom edge, with the rows centered vertically |
| Top mounting-hole row | 125.60 mm above the bottom edge, with the rows centered vertically |
| Vertical mounting-hole pitch | 122.50 mm |
| Leftmost mounting-hole column | 6.90 mm from the left PCB edge; second rail-grid hole from the left |
| Rightmost mounting-hole column | 418.38 mm from the left PCB edge (6.90 mm from the right); second rail-grid hole from the right |

The centered-row calculation is (128.70 - 122.50) / 2 = 3.10 mm. The former 120.00 mm pitch and 4.35 mm edge margins are superseded. Intermediate mounting-hole columns are not specified here.

On the project's SCHROFF card cages, the outermost rail holes at both sides secure the side panels and are unavailable for backplane mounting. Use the next hole inward at each end, a 1 HP (5.08 mm) shift. Confirm screw-head and washer clearance at these positions.

The [SCHROFF EuropacPRO catalog, pages 6.8, 6.32, and 6.35](https://may-static.de/cms/content%20links/baugruppentraeger/td_227.en.pdf) identifies the kit's rear rails and shows the 84 HP insulation strip's end-hole span as 83 x 5.08 = 421.64 mm. With the PCB centered on that grid, the occupied end holes lie (425.28 - 421.64) / 2 = 1.82 mm from each PCB side. Moving one hole inward gives 1.82 + 5.08 = 6.90 mm. These are calculated coordinates for the chosen centered outline, not dimensions quoted from a kit-specific PCB drawing.

The four outer backplane mounting-hole centers are therefore (6.90, 3.10), (6.90, 125.60), (418.38, 3.10), and (418.38, 125.60) mm, measured from the PCB's lower-left corner on the connector side. Their horizontal separation is 411.48 mm. The former 2.54 mm PCB-edge offsets are superseded.

Published references:

- [SCHROFF Design Guide, page 11, Figure 6](https://www.digikey.sg/Site/Global/Layouts/DownloadPdf.ashx?pdfUrl=044BECE460B74307A75CB81661D5BB75): 122.50 mm mounting pitch and connector offsets from pitch references. Its example board height is 128.55 mm.
- [SCHROFF VME/VME64x manual, page 15](https://www.nvent.com/sites/default/files/acquiadam_assets/2021-06/73972-103.pdf): 128.70 mm height for a 3U VME backplane. Thus 128.70 mm is a published implementation size, not the only possible 3U outline.
- [SCHROFF VME assembly drawing, page 2](https://www.nvent.com/sites/default/files/dam/73972-128.pdf): 425.28 mm width for 21 slots, calculated as 21 x 20.32 - 1.44 mm. This 6U drawing supplies the horizontal reference target; it is not a drawing of the project's 3U backplane.

### Connectors and Placement

The backplane uses DIN 41612 receptacles with 96 contacts arranged in three rows of 32, on a 2.54 mm (0.100 in) contact pitch.

The example parts recorded for this design are:

- **Backplane receptacle:** HARTING 09032966825, listed at [DigiKey](https://www.digikey.com/en/products/detail/harting/09032966825/3179780) and [Mouser](https://www.mouser.com/en/ProductDetail/HARTING/09032966825).
- **Card-mounted right-angle plug:** HARTING 09031966921, listed at [DigiKey](https://www.digikey.com/en/products/detail/harting/09031966921/3179738) and [Mouser](https://www.mouser.com/en/ProductDetail/HARTING/09031966921).

The intended placement of the first receptacle is:

| Feature | Offset from first slot pitch reference plane | Offset from bottom edge |
| --- | --- | --- |
| Lower connector mounting hole | 7.62 mm | 19.35 mm |
| Upper connector mounting hole | 7.62 mm | 109.35 mm |
| Contact row b centerline | 7.92 mm | Not specified here |

The connector mounting holes are 90.00 mm apart vertically. Contact row b lies 0.30 mm to the right of the mounting-hole centerline. Each subsequent connector is offset horizontally by 20.32 mm (4 HP, or 0.800 in).

The 19.35 mm and 109.35 mm vertical locations follow from centering the 90 mm hole pair on a 128.70 mm board. These agree with the 16.25 mm separation between each connector mounting hole and the nearest backplane mounting row in the [Amphenol-BSI 3U VME drawing](https://static6.arrow.com/aropdfconversion/5b695883d421994bda990b27afda45dd473ddf9b/vme.pdf).

The horizontal reference must be carried into the PCB layout. Centering the chosen 425.28 mm board within the 426.72 mm allocation gives an inset of 0.72 mm. The first connector's PCB-edge offsets are therefore 7.62 - 0.72 = 6.90 mm for its mounting holes and 7.92 - 0.72 = 7.20 mm for row b. For connector number n (1 through 21), add (n - 1) x 20.32 mm to these offsets. This defines the project's nominal placement; check the assembled card-guide alignment before fabrication.

## Layout Updates Pending

The revised specification returns to 4 HP card spacing. The following differences were recorded during the layout review and identify updates needed to bring the KiCad files into agreement with this specification:

| Item | Revised specification | KiCad value at review |
| --- | --- | --- |
| Backplane outline | 425.28 mm by 128.70 mm, centered on the mounting grid | 428.64 mm by 130.1905 mm |
| Backplane connectors | 21 positions at 20.32 mm (4 HP) pitch | 26 connector footprints, J1-J26, at 15.24 mm (3 HP) pitch |
| Backplane mounting-hole row pitch | 122.50 mm | 122.6109 mm |
| Backplane outer mounting-hole columns | 6.90 mm from each side edge, skipping the occupied end holes | 8.58 mm from each side edge |
| First connector mounting-hole centerline | 6.90 mm from the left PCB edge (7.62 mm from the first slot pitch reference plane) | 8.58 mm from the left edge |
| 12 HP panel width | 60.6 mm | 60.06 mm |
| PCB bracket hole offset from the front edge | 3.56 mm | 3.57 mm |

These measurements come from the [backplane layout](../system/BACKPLANE/BACKPLANE.kicad_pcb), [12 HP panel template](../panels/TEMPLATE_12HP/TEMPLATE_12HP.kicad_pcb), and [card template](../modules/TEMPLATE/TEMPLATE.kicad_pcb). The card template confirms the 160 mm by 100 mm outline, 1.6 mm thickness, 2.7 mm bracket holes, and 88.9 mm hole spacing. The panel template confirms the 128.4 mm height and the stated bracket mounting-hole positions.

The selected subrack is confirmed as 24564-131. The nominal outline and hole coordinates above combine published dimensions with the project's centered-board placement and inward mounting-hole choice. Before fabrication, confirm assembled guide alignment, screw/washer clearance, manufacturing tolerances, and connector fit. This review does not establish full IEC compliance.

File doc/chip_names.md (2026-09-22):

# CHIP NAMES AND MEANINGS

## W65C02

Central Processing Unit (CPU)

The orchestrator, control center, and brain.

### Sophronia

"Self-controlled, prudent, and wise." A perfect fit for a CPU that spends its life strictly fetching, decoding, and executing instructions under tight timing controls without ever losing discipline.

## W65C22

Versatile Interface Adapter (VIA)

The ultimate multitasker. Handles parallel I/O, background timers, and data shifting.

### Millicent

"Strong in work" or "industrious." The VIA is the ultimate workplace laborer of the system, juggling multiple input/output pins, generating interrupts, and clocking pulses behind the scenes.

## W65C51

Asynchronous Communications Interface Adapter (ACIA)

The UART serial controller that speaks to external terminals.

### Eulalia

"Sweetly speaking" or "well-spoken." An eccentric Victorian favorite that perfectly describes a communications chip responsible for cleanly articulating data bits down a serial line.

## MAX232

Dual RS-232 Driver/Receiver

A voltage level shifter. It translates 5V TTL logic up to ±12V serial signals and back.

### Iris

"The rainbow goddess / messenger who bridges worlds." Just as the mythological Iris bridged heaven and earth, this chip acts as a literal bridge between two entirely different voltage domains, translating foreign electrical signals so they can understand each other.

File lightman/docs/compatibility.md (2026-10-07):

# Terminal compatibility baseline

This is an initial useful VT100/VT52 subset, not a conformance-certified DEC
terminal. Use ASCII, 80 columns and 24 rows. Host applications should avoid
features listed as unsupported below. There is no Unicode/UTF-8 decoder.

The implementation follows the
[DEC VT100 User Guide, chapter 3](https://www.vintagecomputer.net/digital/VT100/vt100_manual/chapter3.html).

## Implemented

| Area | Behavior |
| --- | --- |
| C0 controls | BS, HT, LF/VT/FF, CR, SO/SI; BEL flashes the Pico LED |
| ANSI cursor | CUU/CUD/CUF/CUB, CUP/HVP, index, reverse index, next line |
| Erasing | ED and EL modes 0, 1, 2 |
| Scrolling | DECSTBM top/bottom margins; origin-relative addressing; delayed wrap |
| Attributes | SGR reset, bold (bold font), underline, blink, reverse; 22/24/25/27 resets |
| Tabs | Every eight columns by default; ESC H; CSI 0g/3g |
| Saved state | ESC 7/8: cursor, rendition, origin/wrap modes and G0/G1 selection |
| Modes | DECCKM, DECANM, DECOM, DECAWM, DECSCNM, LNM, keyboard lock; cursor visibility extension |
| Identification | DA replies ESC [ ? 1 ; 0 c (VT100, no options); DSR 5/6 |
| Character sets | G0/G1 ASCII and DEC special graphics, SO/SI selection |
| Reset/test | RIS (ESC c); DECALN (ESC # 8) |
| VT52 | ESC A/B/C/D, H, I, J, K, Y row/column, Z, F/G, =/>, < |
| VT52 identity | ESC / Z; ESC < enters ANSI mode; ANSI CSI ? 2 l enters VT52 |
| Keys | US set 2 PS/2 typing, Shift/Caps/Ctrl/Alt, arrows, F1–F4 as PF1–PF4 |
| Keypad | Numeric/application digits, decimal, minus, Enter; ANSI/VT52 forms |
| Additional PC keys | Home, End, Insert, Delete, Page Up/Down use common ANSI extensions |

Alt prefixes transmitted key sequences with ESC. F12 is always local setup,
even with host keyboard lock active. Backspace sends DEL by default and can
be changed to BS in setup. Enter sends CR, or CR/LF when the host enables LNM.
Keypad plus, multiply and divide remain literal characters; Num Lock does not
change the numeric keypad. Caps Lock is tracked locally without setting the
keyboard's LED. Holding keys uses the keyboard's own repeat behavior.

DEC box-drawing, scan lines, diamond and checkerboard glyphs are drawn locally.
Some mathematical/control-picture symbols are ASCII approximations. VT52 F/G
uses the same graphics repertoire, rather than a distinct historical VT52 ROM.

## Deliberate gaps

- 132-column mode, double-width/double-height lines, smooth scrolling.
- Exact historical VT52 graphics, UK national character set, full DEC font ROM.
- ANSI color SGR, Unicode, alternate screen, scrollback, and xterm features.
- VT102 insert/delete characters and lines, printer support, answerback,
  keyboard LED commands, confidence tests and serial BREAK generation.
- USB keyboard input, keyboard host commands, non-US layouts and F5–F11.
- Modem dialing, automatic carrier/ring handling and DTR hangup control.

Unsupported CSI sequences are consumed without printing them. CSI parameter
count/value limits prevent malformed streams from overrunning buffers. OSC/DCS
strings are discarded through BEL or ST. CAN/SUB abort an in-progress sequence.

## Communication and storage

Default: **9600 baud, 8N1, no flow control, VT100, no local echo, DEL Backspace,
regular font, amber normal text**. Setup supports 300–115200 baud, 7/8 bits, 1/2 stop
bits, none/even/odd parity and no/software/hardware flow control.

Normal color selects White, Classic green, Yellow, Amber, Red, Blue, Cyan or
Magenta through the RGB332 DACs. It sets the base foreground on black for the
whole terminal, including attributes and cursor; reverse swaps foreground and
background. This does not add ANSI color SGR support. The menu previews draft
colors and restores the applied color on cancel. Legacy saved color indices
0/1/2 retain White/Green/Yellow; new presets extend the same settings record.
Existing saved choices take precedence over the new amber factory default.

The RX ring holds 4095 bytes and TX ring 1023 bytes. XON/XOFF and software-driven
RTS use 75%/25% RX thresholds. UART hardware gates outgoing bytes on CTS when
selected. Flow-control characters bypass a paused TX queue. Setup requests
that the peer pause; incoming data still updates the separate terminal buffer.
Overrun/framing/parity errors and queue drops appear in setup. An overflowing
TX queue discards a complete key/reply sequence, never just its suffix.

DSR, DCD and RI are active-low status inputs displayed live in setup. They do
not gate serial traffic or trigger modem actions. RI is sampled, not latched;
brief pulses between display updates may not be visible. DTR stays asserted.

Pause host output before applying framing changes or saving. Saving erases
flash with interrupts temporarily disabled and video stopped, so an
uncooperative host can lose data. The VGA monitor may briefly lose sync.
Two alternating 4 KiB sectors at flash offsets 0x1FE000 and 0x1FF000 store
versioned, CRC32-checked records. The previous record remains intact during
the next erase/write. Invalid records fall back to defaults; a linker assertion
prevents firmware growth into these sectors. Ordinary UF2 updates leave the
settings area untouched, but a full-chip erase removes settings.

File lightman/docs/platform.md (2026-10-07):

# Pico platform decision

The original Raspberry Pi Pico, based on RP2040, was selected on 2026-10-05.
Its two cores, PIO, DMA and hardware UART allow a fixed VGA signal while the
terminal processes serial input and keyboard events.

The firmware uses the Pico C SDK directly. PIO0 streams all ten consecutive
VGA GPIOs (13–22: HS, VS, R0..R2, G0..G2, B0..B1) from two DMA scanline buffers
at a 25.2 MHz pixel clock. Each pixel is a 16-bit DMA transfer: ten output bits
and six discarded bits, with a 16-bit PIO autopull threshold. The system
clock is 126 MHz; each PIO pixel takes five cycles. Core 1 expands pre-rendered
packed pixel rows and rearms alternating DMA channels. It does not parse text,
access flash font data, or block waiting for the terminal's frame publisher.

Core 0 owns terminal state, US PS/2 scan-code decoding, UART queues and setup.
It renders complete 640x384 monochrome rasters into a three-buffer pool, then
publishes an index under a short hardware spinlock. Core 1 adopts the latest
published raster at a frame boundary; the buffer it scans is never modified.
Three rasters cost about 90 KiB. Each frame also carries its normal-color
selection. Eight RGB332 presets expand glyph rows through a 32 KiB lookup
table; two 800-pixel halfword scanline buffers use 3,200 bytes. The raster stays
1 bit per pixel, with a single selected foreground and black background.
This leaves room in the RP2040's 264 KiB SRAM for fonts, terminal state, I/O
queues and stacks. Core 0 and
core 1 each reserve a 4 KiB stack. No RTOS or pico-extras dependency is needed.

Serial RX and PS/2 falling edges use core 0 interrupts. Queues keep interrupts
short and separate byte capture from parsing. UART0 CTS gates hardware TX;
RTS is a GPIO so it reflects the software RX queue rather than only the UART
FIFO. DTR remains asserted; DSR, DCD and RI are sampled and displayed in setup.

Saving settings stops VGA DMA and parks core 1 in an SRAM loop with interrupts
disabled. Core 0 then disables its interrupts for the SDK flash erase/program
calls, restores interrupts, verifies the write, and resumes VGA. The last two
4 KiB flash sectors are reserved by a linker assertion. See
[compatibility](compatibility.md) for the implications for uninterrupted serial
traffic during saves.

This design has been cross-compiled and its portable logic tested. Physical
VGA timing, analog levels and sustained-load timing margins still require the
[bench checks](../tests/bringup.md).

References: [Pico SDK hardware APIs](https://www.raspberrypi.com/documentation/pico-sdk/hardware.html),
[Pico-series documentation](https://www.raspberrypi.com/documentation/microcontrollers/pico-series.html).

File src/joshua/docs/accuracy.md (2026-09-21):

# Accuracy and validation

Status: initial implementation, validated on Linux on 2026-09-21. This file records
what was actually tested and where the emulation is incomplete. Passing
instruction tests does not establish complete electrical or peripheral accuracy.

## CPU evidence

The following independent test binaries reached their documented success loops:

| Test | Load / entry | Success PC |
| --- | --- | --- |
| Klaus Dormann 6502 functional test | `$0000` / `$0400` | `$3469` |
| Klaus Dormann 65C02 extended-opcode test | `$0000` / `$0400` | `$24F1` |

Upstream: [6502_65C02_functional_tests](https://github.com/Klaus2m5/6502_65C02_functional_tests),
revision `7954e2dbb49c469ea286070bf46cdd71aeb29e4b`. The test binaries were
downloaded outside the project and are not redistributed here. Their SHA-256s:

```text
6502_functional_test.bin
fa12bfc761e6f9057e4cc01a665a7b800ff01ae91f598af1e39a1201d01953fd
65C02_extended_opcodes_test.bin
10a2a07fa240666fa610c46accebe8d42b1000feef3aae619da15a8d152869b2
```

The [SingleStepTests WDC 65C02 vectors](https://github.com/SingleStepTests/65x02/tree/2f6980a2d95757486c7bee24355c360e40e2a224/wdc65c02/v1)
were run at revision `2f6980a2d95757486c7bee24355c360e40e2a224`: 254 files, 10,000
cases each. The runner compares all registers, expected memory and the address,
data and direction of every bus access.

- **2,530,000 cases passed** all comparisons, covering 253 opcode encodings.
- All **10,000 `$5C` cases matched functional state but failed bus timing** because
  the reference uses four cycles and Joshua uses the datasheet's eight cycles.
- The external data set does not cover WAI/STP. Local tests cover their basic
  entry, wait, NMI wakeup and reset behavior.

The `$5C` discrepancy is unresolved. The [WDC W65C02S datasheet](https://www.westerndesigncenter.com/documentation/w65c02s.pdf),
Table 7-1, specifies eight cycles. Joshua retains that count. Its filler read
addresses for this encoding have not been verified on IMNOTWOPR hardware. Do not
use reserved `$5C` for calibrated delays until the installed CPU is measured.
The external vector runner intentionally reports this mismatch as a failure; it
does not silently waive it.

The CPU includes the documented CMOS instructions and bit operations, decimal
ADC/SBC, page-cross timing, CMOS RMW bus accesses, fixed indirect JMP behavior,
stack operations, BRK/IRQ/NMI/reset, WAI, STP and reserved NOP lengths. Register and
memory tests include arbitrary decimal operands in the upstream vectors.

Remaining CPU work includes precise IRQ/NMI sampling windows, externally timed
reset, RDY stalls, SO/BE/VPB/MLB pin behavior, single-cycle suspension, WAI wake
latency, and physical-hardware comparison. Current IRQ/NMI decisions happen at
instruction boundaries. No pin-level cycle-accuracy claim is made.

## Peripheral coverage

| Device | Implemented | Remaining / simplified |
| --- | --- | --- |
| RAM/ROM | Arbitrary non-overlapping regions, protection, debugger patching, raw images | Aliases, overlays and bank switching |
| W65C22 | Port data/direction, T1 one-shot/free-run/PB7, T2 interval/PB6 pulse count, IFR/IER, read acknowledgements | Shift register operation, input latching, CA/CB handshakes, physical pin timing |
| W65C51N | Data/status/command/control, emulated frame durations, RX full/overrun/IRQ, always-set TDRE, premature TX overwrite | Bit-level framing/errors, echo, parity, TX break/IRQ, dynamic CTS/DCD/DSR and programmable reference clock |

VIA shift/input-latch activation and nonzero PCR modes currently raise an explicit
error. ACIA echo, parity enable, transmitter IRQ and break modes also raise an
error. VIA inputs default high and can be supplied through the core's port APIs;
there is no external hardware attached to those ports in the console application.

The UART assumes a 1.8432 MHz reference and connected modem lines. Frames have
5–8 data bits and the configured stop-bit duration. When the control register
selects the external receiver clock, the model assumes 115200 baud. Durations are
rounded up to an integer CPU cycle. Host bytes queue before transmission, but the
emulated receiver has a single data register and can overrun. These are explicit
byte-endpoint approximations, not an electrical RS-232 model.

References: the repository's [hardware datasheets](../../../doc/DataSheets),
[WDC VIA datasheet](https://www.westerndesigncenter.com/documentation/w65c22.pdf)
and [WDC ACIA datasheet](https://www.westerndesigncenter.com/wdc/documentation/w65c51n.pdf).

## Local regression tests

The CTest suite passes in GCC 14 Debug and GCC 13 Release builds, both in C++23
mode. It also passes with GCC 14 AddressSanitizer and UndefinedBehaviorSanitizer
(including leak checking, run outside the sandbox because LeakSanitizer does not
support process tracing). It covers:

- Reset and representative instruction/decimal/branch/RMW timing and bus traces.
- All 256 opcode encodings through assembly/disassembly round trips.
- ROM protection, unmapped reads, overlap/range rejection and atomic failed edits.
- VIA timer IRQs, free-run reloads and non-destructive inspection.
- ACIA receive, status acknowledgement, timed transmit and overwrite behavior.
- Monitor commands, breakpoint editing and resuming past an execution breakpoint.
- File round trips, relative profile images and CLI precedence in either order.
- Serial echo through the actual application.
- Linux pseudo-terminal entry/exit, Ctrl-C delivery and terminal restoration.

The Windows/UCRT64 build and native console behavior remain unverified on a
Windows host. The C++ core has no POSIX dependency; terminal implementations are
selected with `_WIN32`.

## Reproducing external tests

For either functional ROM, use an all-RAM machine. Example for the extended test,
with a locally downloaded binary:

```sh
./build/release/joshua --ram 0:10000:/path/65C02_extended_opcodes_test.bin \
  --rom none --via none --acia none --unthrottled --cycles 100000000
```

Then enter:

```text
break 24f1
run 400
regs
quit
```

The success stop must be `Breakpoint at $24F1`, not merely a cycle-limit stop. For
the base test, use `$3469` and a budget of 150000000 cycles. Test binaries and
success addresses are tied to the revision above.

For locally downloaded WDC JSON vectors:

```sh
python3 tests/check_vectors.py build/release/joshua_vectors /path/wdc65c02/v1/*.json
```

The expected current result is 253 passing files and the explicit `$5C` timing
failure described above. The build never downloads test data. The vector runner
uses only Python's standard library and the native C++ harness.

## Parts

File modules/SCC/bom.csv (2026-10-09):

Reference | Value | Datasheet | Footprint | Qty | DNP
C1,C14,C16 | 47µF |  | IMNOTWOPR:CP_Radial_Tantal_P100mil | 3
C2,C4,C6,C8,C9,C10,C11,C12,C13,C15,C17 | 100n |  | IMNOTWOPR:C_Rect_P200mil | 11
C3,C7 | 10n |  | IMNOTWOPR:C_Rect_P200mil | 2
C5 | 1u |  | IMNOTWOPR:C_Rect_P200mil | 1
D1 | LED_G |  | IMNOTWOPR:Wire_LED | 1
D2,D4 | 1N4148 | https://www.diodes.com/assets/Datasheets/ds12019.pdf | FormantKO:DO-35_P400mil | 2
D3 | LED_R |  | IMNOTWOPR:Wire_LED | 1
D5 | LED |  | IMNOTWOPR:Wire_LED | 1
J1 | CardConnector |  | IMNOTWOPR:SystemConector_Male | 1
MES1,MES2,MES3,MES4 | Voltmeter_DC |  | IMNOTWOPR:Wire_Meter | 4
MH1 | CardBracket |  | IMNOTWOPR:CardBracket | 1
R1,R4,R5 | 430R |  | IMNOTWOPR:R_Axial_DIN0207_P400mil | 3
R2 | 10k |  | IMNOTWOPR:R_Axial_DIN0207_P400mil | 1
R3 | 91k |  | IMNOTWOPR:R_Axial_DIN0207_P400mil | 1
SW1 | 1MS2T1B1M1QES |  | IMNOTWOPR:Wire_SW_SPDT | 1
SW2 | 1MS1T1B1M1QES |  | IMNOTWOPR:Wire_SW_SPST_23 | 1
U1 | 74HCT14 | http://www.ti.com/lit/gpn/sn74HC14 | IMNOTWOPR:DIP-14N | 1
U2 | 74HCT00 | http://www.ti.com/lit/gpn/sn74hc00 | IMNOTWOPR:DIP-14N | 1
U3 | 555 | http://www.ti.com/lit/ds/symlink/ne555.pdf | IMNOTWOPR:DIP-8N | 1
U4,U5,U6 | 74HCT390 | https://www.ti.com/lit/ds/symlink/cd74hct390.pdf | IMNOTWOPR:DIP-16N | 3
U7 | 74AHCT541 | http://www.ti.com/lit/gpn/sn74HCT541 | IMNOTWOPR:DIP-20N | 1
Y1 | 1Mhz | http://www.conwin.com/datasheets/cx/cx030.pdf | Oscillator:Oscillator_DIP-14 | 1

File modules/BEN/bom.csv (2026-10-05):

Reference | Value | Datasheet | Footprint | Qty | DNP
C1,C3,C4 | 47u |  | IMNOTWOPR:CP_Radial_Tantal_P100mil | 3
C2,C5,C6,C7,C8,C9,C10,C11,C12,C13,C14,C15,C16,C17,C18,C19,C20,C21,C22,C23,C24,C25 | 100n |  | IMNOTWOPR:C_Rect_P200mil | 22
C26 | 30pF |  | IMNOTWOPR:C_Rect_P200mil | 1
D1,D6 | 1N5817 | http://www.diodes.com/_files/datasheets/ds23022.pdf | Diode_THT:D_DO-41_SOD81_P10.16mm_Horizontal | 2
D2,D3,D4,D5,D7,D8,D9,D10 | LED_G |  | IMNOTWOPR:LED_D5.0mm_Horizontal_O1.27mm_Z3.0mm,IMNOTWOPR:LED_D5.0mm_Horizontal_O3.81mm_Z9.0mm | 8
D11,D12,D13,D14,D15,D16,D17,D18 | LED_R |  | IMNOTWOPR:LED_D5.0mm_Horizontal_O1.27mm_Z3.0mm,IMNOTWOPR:LED_D5.0mm_Horizontal_O3.81mm_Z9.0mm | 8
J1 | CardConnector |  | IMNOTWOPR:SystemConector_Male | 1
J2 | Conn_01x04 |  | Connector_PinSocket_2.54mm:PinSocket_1x04_P2.54mm_Vertical | 1
J3 | IDC DE9 Female |  | Connector_PinHeader_2.54mm:PinHeader_2x05_P2.54mm_Vertical | 1
MH1 | CardBracket |  | IMNOTWOPR:CardBracket | 1
R1,R2,R3,R4,R5,R6,R7,R8,RN2 | 1k | http://www.vishay.com/docs/31509/csc.pdf | IMNOTWOPR:R_Axial_DIN0207_P400mil,Resistor_THT:R_Array_SIP9 | 9
R9 | 1M |  | IMNOTWOPR:R_Axial_DIN0207_P400mil | 1
RN1 | 10kΩ | http://www.vishay.com/docs/31509/csc.pdf | Resistor_THT:R_Array_SIP9 | 1
RN3 | 10k | http://www.vishay.com/docs/31509/csc.pdf | Resistor_THT:R_Array_SIP9 | 1
RN4 | 1k5 | http://www.vishay.com/docs/31509/csc.pdf | Resistor_THT:R_Array_SIP9 | 1
SW1 | PAGE SELECT |  |  | 1
SW2,SW3,SW4,SW5,SW6,SW7,SW8,SW9 | 2MS1T1B1M1QES |  | IMNOTWOPR:PanelConnector_1x03 | 8
U1 | 74HCT13 | http://www.ti.com/lit/gpn/sn74LS13 | IMNOTWOPR:DIP-14N | 1
U2 | 28C256 | http://ww1.microchip.com/downloads/en/DeviceDoc/doc0006.pdf | IMNOTWOPR:ZIF-28W | 1
U3 | 74HCT32 | http://www.ti.com/lit/gpn/sn74LS32 | IMNOTWOPR:DIP-14N | 1
U4 | 62256 | https://ecee.colorado.edu/~mcclurel/Cypress_SRAM_CY62256.pdf | IMNOTWOPR:DIP-28W | 1
U5 | 74HCT00 | http://www.ti.com/lit/gpn/sn74hc00 | IMNOTWOPR:DIP-14N | 1
U6 | MC1488 |  | FormantKO:DIP-14N | 1
U7,U8 | 74AHCT541 | http://www.ti.com/lit/gpn/sn74HCT541 | IMNOTWOPR:DIP-20N | 2
U9 | 74AHCT245_Slave | http://www.ti.com/lit/gpn/sn74HC245 | IMNOTWOPR:DIP-20N | 1
U10 | W65C22 | https://www.westerndesigncenter.com/wdc/documentation/w65c22.pdf | IMNOTWOPR:DIP-40W | 1
U11 | 74HCT688 | https://www.ti.com/lit/ds/symlink/cd54hc688.pdf |  | 1
U12 | W65C51 | https://www.westerndesigncenter.com/wdc/documentation/w65c51n.pdf | IMNOTWOPR:DIP-28W | 1
U13 | MC1489 |  | FormantKO:DIP-14N | 1
U14 | 74HCT138 | http://www.ti.com/lit/ds/symlink/cd74hc238.pdf |  | 1
Y1 | 1.8432Mhz | ee |  | 1

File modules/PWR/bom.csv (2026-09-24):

Reference | Value | Datasheet | Footprint | Qty | DNP
C1 | 47µF |  | FormantKO:CP_Radial_Tantal_P200mil | 1
C2 | 100n |  | IMNOTWOPR:C_Rect_P200mil | 1
C3 | 100nF |  | IMNOTWOPR:C_Rect_P200mil | 1
D1 | PWR STANDBY |  | IMNOTWOPR:PanelConnector_1x02 | 1
D2 | PWR OK |  | IMNOTWOPR:PanelConnector_1x02 | 1
J1 | CardConnector |  | IMNOTWOPR:SystemConector_Male | 1
JP1 | I2C PULLUP |  | IMNOTWOPR:Jumper_1x02 | 1
MES1 | +5V METER |  | IMNOTWOPR:PanelConnector_1x02 | 1
MES2 | +12V METER |  | IMNOTWOPR:PanelConnector_1x02 | 1
MES3 | -12V METER |  | IMNOTWOPR:PanelConnector_1x02 | 1
MES4 | +12V2 METER |  | IMNOTWOPR:PanelConnector_1x02 | 1
MH1 | CardBracket |  | IMNOTWOPR:CardBracket | 1
R1,R2,R3 | 1kΩ |  | IMNOTWOPR:R_Axial_DIN0207_P400mil | 3
R4,R5 | 4k7Ω |  | IMNOTWOPR:R_Axial_DIN0207_P400mil | 2
SW1 | PWR ON |  | IMNOTWOPR:PanelConnector_1x03 | 1
SW2 | RESET |  | IMNOTWOPR:PanelConnector_1x03 | 1
U1 | 74HCT00 | http://www.ti.com/lit/gpn/sn74hc00 | IMNOTWOPR:DIP-14N | 1

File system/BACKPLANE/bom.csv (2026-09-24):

Reference | Qty | Value | DNP | Exclude from BOM | Exclude from Board | Footprint | Datasheet
J1,J2,J3,J4,J5,J6,J7,J8,J9,J10,J11,J12,J13,J14,J15,J16,J17,J18,J19,J20 | 20 | BusConnector |  |  |  | IMNOTWOPR:SystemConnector_Female
J21 | 1 | ATX-08 |  |  |  | IMNOTWOPR:ATX-08
J29 | 1 | ATX-24 |  |  |  | IMNOTWOPR:ATX-24 | https://www.intel.com/content/dam/www/public/us/en/documents/guides/power-supply-design-guide-june.pdf
JP1 | 1 | I2C PULLUPS |  |  |  | FormantKO:Jumper_1x02
R1,R2 | 2 | 4k7Ω |  |  |  | IMNOTWOPR:R_Axial_DIN0207_P400mil

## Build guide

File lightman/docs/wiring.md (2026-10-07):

# Lightman prototype wiring

These assignments target the original 2 MiB Raspberry Pi Pico. Numbers below
are GPIO numbers, not physical header positions. Firmware assignments live in
[`lightman_pico.h`](../firmware/boards/lightman_pico.h). The serial interface
uses three MAX3232s for the full DE-9 signal set. Check the PCB against these
assignments before assembly.

| Signal | GPIO | Pico physical pin | Destination |
| --- | ---: | ---: | --- |
| UART0 TX | 0 | 1 | MAX3232 driver input -> DE-9 pin 3 |
| UART0 RX | 1 | 2 | MAX3232 receiver output <- DE-9 pin 2 |
| CTS | 2 | 4 | MAX3232 receiver output <- DE-9 pin 8 |
| RTS | 3 | 5 | MAX3232 driver input -> DE-9 pin 7 |
| DSR | 4 | 6 | MAX3232 receiver output <- DE-9 pin 6 |
| DTR | 5 | 7 | MAX3232 driver input -> DE-9 pin 4 |
| DCD | 6 | 9 | MAX3232 receiver output <- DE-9 pin 1 |
| RI | 7 | 10 | MAX3232 receiver output <- DE-9 pin 9 |
| PS/2 clock | 8 | 11 | Open-drain level shifter <-> keyboard clock |
| PS/2 data | 9 | 12 | Open-drain level shifter <-> keyboard data |
| VGA HSYNC | 13 | 17 | VGA pin 13 |
| VGA VSYNC | 14 | 19 | VGA pin 14 |
| VGA R0 | 15 | 20 | 3-Bit DAC_R0 -> VGA pin 1 |
| VGA R1 | 16 | 21 | 3-Bit DAC_R1 -> VGA pin 1 |
| VGA R2 | 17 | 22 | 3-Bit DAC_R2 -> VGA pin 1 |
| VGA G0 | 18 | 24 | 3-Bit DAC_G0 -> VGA pin 2 |
| VGA G1 | 19 | 25 | 3-Bit DAC_G1 -> VGA pin 2 |
| VGA G2 | 20 | 26 | 3-Bit DAC_G2 -> VGA pin 2 |
| VGA B0 | 21 | 27 | 2-Bit DAC_B0 -> VGA pin 3 |
| VGA B1 | 22 | 29 | 2-Bit DAC_B1 -> VGA pin 3 |
| Common ground | GND | e.g. 3 | DE-9 pin 5, keyboard ground, VGA grounds |

## Serial

On GPIO0/1/2, the RP2040 hardware UART0 functions are fixed as TX/RX/CTS;
these signals cannot be swapped within those pins in firmware. Keep the PCB
connections in the order above. RTS is a software-controlled output on GPIO3.
DTR and DSR use ordinary GPIOs and are assigned to GPIO5 and GPIO4 respectively
to suit the board layout.

The male DE-9 is **DTE**: TX on pin 3, RX on pin 2. A DTE host such as a PC
normally needs a null-modem cable (TX/RX crossed; handshake signals crossed
appropriately if used). A DCE device uses a straight-through connection.

Schematic transceiver allocation:

| IC channel | Driver | Receiver |
| --- | --- | --- |
| U1 channel 1 | TX | RX |
| U1 channel 2 | RTS | CTS |
| U3 channel 1 | DTR | DSR |
| U3 channel 2 | Spare | Spare |
| U5 channel 1 | Spare | DCD |
| U5 channel 2 | Spare | RI |

Three MAX3232s provide the three drivers and five receivers needed for all
eight DE-9 signals. The third chip receives DCD (DE-9 pin 1) and RI (pin 9).
See the [MAX3232 datasheet](https://www.ti.com/lit/ds/symlink/max3232.pdf).

Use 3.3 V transceiver supplies so receiver outputs are safe for the Pico.
Fit the charge-pump capacitors specified for the particular part and supply.
Never connect RS-232 voltages directly to GPIO. RTS and DTR are asserted by a
low GPIO level, which the driver converts to positive RS-232 voltage. CTS,
DSR, DCD and RI are asserted when their receiver outputs are low. DTR stays
asserted; DSR, DCD and RI are informational in setup and do not gate serial
traffic. RI shows the current input level, not a latched ring event. With no
handshake wiring, select None or XON/XOFF flow control. CTS/DSR/DCD/RI GPIOs
have pull-ups.

## Keyboard

Standard PS/2 mini-DIN-6 signals are pin 1 data, pin 3 ground, pin 4 +5 V,
and pin 5 clock. Confirm the connector footprint's mating/solder-side numbering
before layout. Use level shifting suitable for open-drain signals and pull-ups
on both voltage domains. The Pico side must stay at 3.3 V. Budget a regulated
5 V keyboard supply and common ground; do not feed 5 V to Pico GPIO.

The initial driver receives the keyboard's default scan-code set 2 and does
not send commands. Use a native PS/2 keyboard that starts scanning in set 2.
Keyboard LEDs, host-controlled repeat settings and USB-only keyboards with a
passive PS/2 adapter are not supported. Clock and data remain inputs.

## VGA

GPIO13–22 must remain consecutive in HS, VS, R0, R1, R2, G0, G1, G2, B0, B1
order for the PIO program. RGB332 provides three red, three green and two blue
bits. The GPIO and physical-pin assignments above match the schematic netlist.
**In this schematic, R0/G0/B0 are the most significant channel bits**, not the
least significant: their smaller resistors give them the greatest weight.

Each GPIO feeds its own resistor, with the outputs summed at the VGA color pin:

| Channel | Most significant bit | Middle bit | Least significant bit |
| --- | --- | --- | --- |
| Red | R0: R4, 470 ohms | R1: R5, 1 kohm | R2: R6, 2.2 kohms |
| Green | G0: R7, 470 ohms | G1: R8, 1 kohm | G2: R9, 2.2 kohms |
| Blue | B0: R10, 390 ohms | — | B1: R11, 1 kohm |

These are the schematic's resistor values; do not use the previous single
270-ohm resistor per channel. With ideal 3.3 V GPIO drive and a 75-ohm monitor
termination, all bits high gives approximately 0.699 V on red/green and 0.696 V
on blue. The chosen resistor ratios approximate binary weights. Measure levels
and color balance on the actual circuit. Sync is 3.3 V logic with
negative polarity; RGB is blanked during sync and porches. Connect VGA signal
grounds (including pins 5, 6, 7, 8 and 10) appropriately. VGA/DDC and EDID are
not implemented; this is a fixed timing source.

Timing is 640 visible + 16 front porch + 96 sync + 48 back porch = 800 pixels;
480 visible + 10 front porch + 2 sync + 33 back porch = 525 lines. At 25.2 MHz
this is 31.5 kHz horizontal and 60 Hz vertical. The 80x24 text image occupies
640x384 pixels, centered vertically. PIO0 uses one state machine and two DMA
channels; core 1 handles scanlines, while core 0 handles the terminal and input.
Each DMA transfer is one 16-bit pixel: bits 0/1 are HS/VS, bits 2–9 are the
eight color GPIOs in the order above, and bits 10–15 are discarded. PIO still
uses five system-clock cycles per pixel at 126 MHz. Firmware converts standard
`RRRGGGBB` RGB332 values into this GPIO order.

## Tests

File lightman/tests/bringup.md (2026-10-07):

# Hardware acceptance checks

Desktop tests and cross-compilation do not verify electrical or real-time
behavior. Perform these checks before relying on the prototype.

1. Confirm the pin map in [wiring](../docs/wiring.md), level-shifter supplies,
   PS/2 pull-ups, all three MAX3232 charge pumps and VGA resistor values.
   Confirm TX/RX reach GPIO0/1, CTS/RTS GPIO2/3 and DTR/DSR GPIO5/4.
   Confirm DCD/RI reach GPIO6/7 and PS/2 clock/data reach GPIO8/9.
   Confirm HS/VS reach GPIO13/14, R0..R2 GPIO15..17, G0..G2 GPIO18..20 and
   B0..B1 GPIO21/22. Channel 0 must feed the smallest resistor (greatest weight).
2. Flash the UF2. Confirm 31.5 kHz HSYNC and 60 Hz VSYNC, negative polarity,
   proper RGB blanking and a stable 80x24 picture. `VGA late` in setup should
   stay zero during scrolling, keyboard activity and repeated menu changes.
   In setup select White and check all three color channels near 0.7 V into
   75 ohms on lit pixels; black, porches and sync must blank all eight RGB bits.
   Check Red/Classic green/Blue for isolated channels, then Amber for full red,
   G0 only and blue off. Amber should differ visibly from Yellow.
3. On a native PS/2 keyboard check letters, digits, shifted punctuation,
   independent left/right Shift and Ctrl, Caps Lock, Ctrl-C, arrow/PF keys,
   keypad application mode, and F12 setup. Disconnect/reconnect and verify BAT
   resets modifiers. Check parity/timeout recovery using a signal generator
   if available. No LED updates are expected on the keyboard itself.
4. Connect DE-9 TX/RX loopback (pins 3/2), default 9600 8N1, local echo off.
   Typed characters should return once. Then test a null-modem-connected host.
5. At each supported baud/framing combination, match the host settings and
   send known patterns. Test 115200-baud sustained text, full-screen scrolling,
   cursor addressing, reverse/underline/blink, and simultaneous keyboard use.
   Monitor RX/TX errors and VGA late counts.
6. Test XON/XOFF in both directions. Send XOFF while typing, then XON; queued
   keys must arrive in order. Open/close setup and confirm the host pauses and
   resumes. A host that ignores flow control may overflow RX; verify the
   counter reports it. Repeated settings changes must not strand the peer in
   XOFF state.
7. Wire RTS/CTS and test gating with CTS deasserted. Resume CTS and verify
   queued characters arrive. Confirm RTS deasserts under RX pressure/setup,
   DTR stays asserted, and DSR status follows the input. Independently assert
   and deassert DCD (DE-9 pin 1) and RI (pin 9) through their receivers: setup
   must show each asserted when its GPIO is low and inactive when high.
   Confirm serial traffic and keyboard input continue in both states. Hold RI
   long enough to observe a display update; its status is not latched.
   No CTS wiring means hardware flow control should remain disabled.
8. Send `ESC [ ? 2 l`, test VT52 cursor addressing and identity, then `ESC <`
   to return to VT100. Run the host's VT100 test program and compare failures
   to the [declared gaps](../docs/compatibility.md); do not claim full vttest
   compliance.
9. In setup cycle all eight Normal color choices in both directions, including
   wraparound. Confirm the preview, cancel, then apply; cancel must restore the
   previous display. Check reverse, bold, underline, blink and cursor in the
   selected color. Restore factory defaults and verify Amber is selected;
   cancel must retain the previous configuration. Apply/save factory defaults
   and verify Amber after reboot. Existing saved White/Green/Yellow choices
   should survive the firmware update. Save settings, power-cycle, verify
   persistence. Alternate
   saved configurations and interrupt power during a save: the last intact
   record should load. Reflash UF2 and check settings remain intact.
10. After flash save verify video recovers, the keyboard still works and serial
    flow resumes. Test with the host paused; separately establish how a peer
    ignoring the pause affects RX error counts.

For a host serial smoke test (replace the serial device as appropriate):

```sh
stty -F /dev/ttyUSB0 9600 cs8 -parenb -cstopb -crtscts -ixon -ixoff raw -echo
printf '\033[2J\033[HLightman test\r\n\033[7mReverse\033[0m\r\n' > /dev/ttyUSB0
printf '\033(0lqqqqk\r\nx    x\r\nmqqqqj\033(B\r\n' > /dev/ttyUSB0
```

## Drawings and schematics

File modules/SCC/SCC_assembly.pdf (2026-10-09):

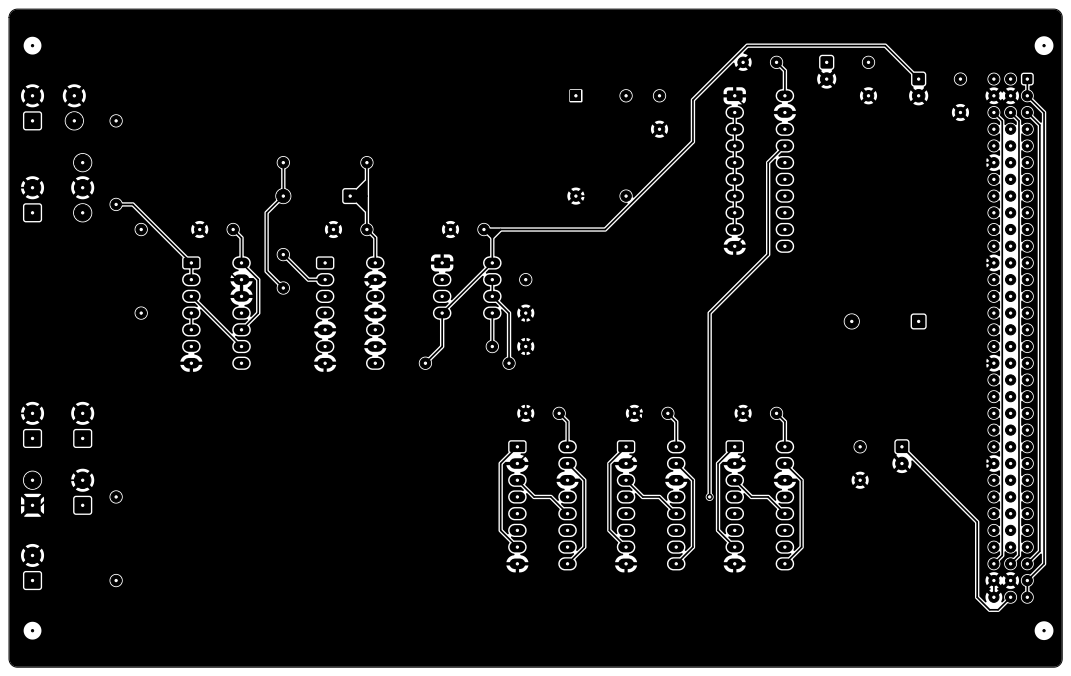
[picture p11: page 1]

DO NOT FOLD, SPINDLE OR MUTILATE
SYSTEM CONTROL CARD
IMNOTWOPR
THE HOUSE OF GALAHAD
Sheet:
File: SCC.kicad_pcb
Title: SCC

Size: A4 | Rev: B
KiCad E.D.A. 10.0.6 | Id: 1/8

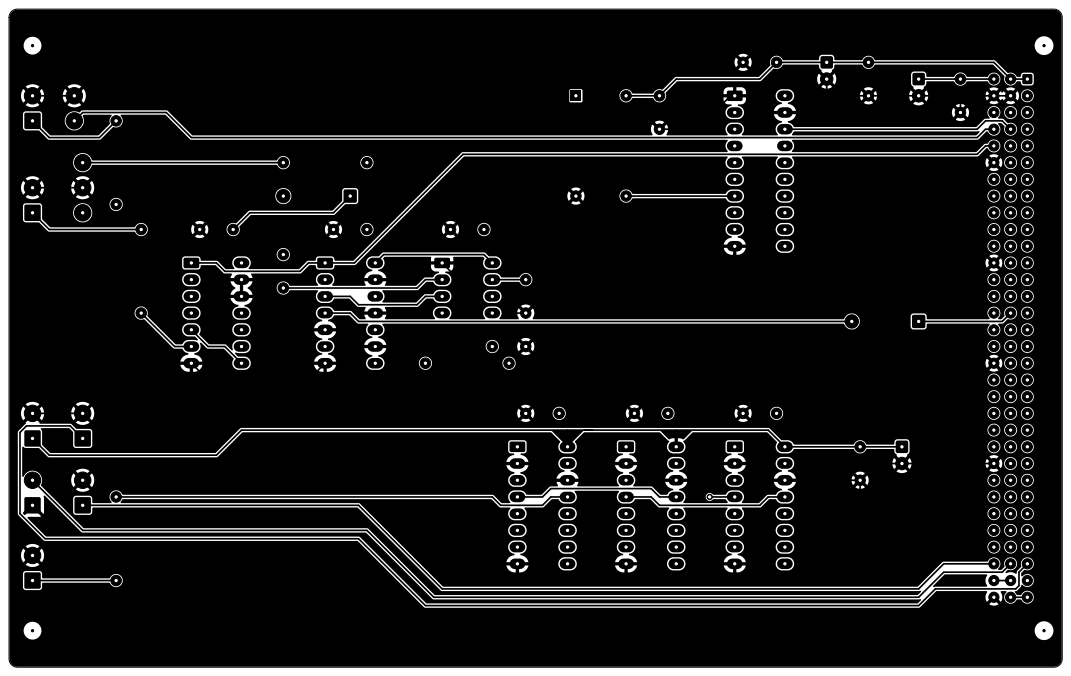
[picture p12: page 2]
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

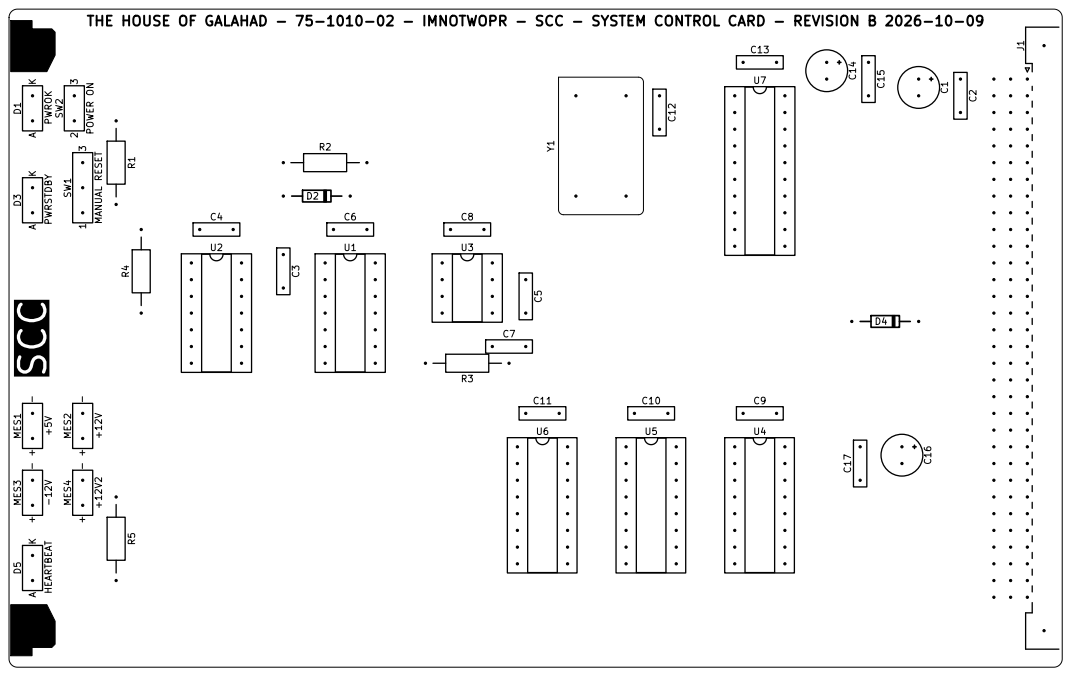
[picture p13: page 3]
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

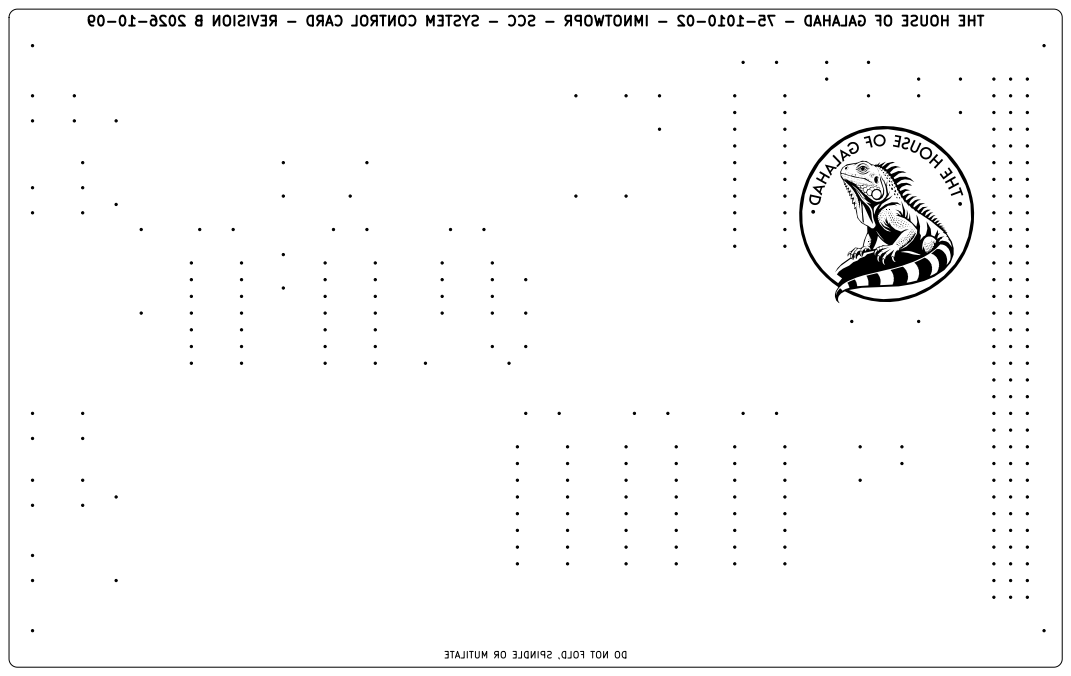
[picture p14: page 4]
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

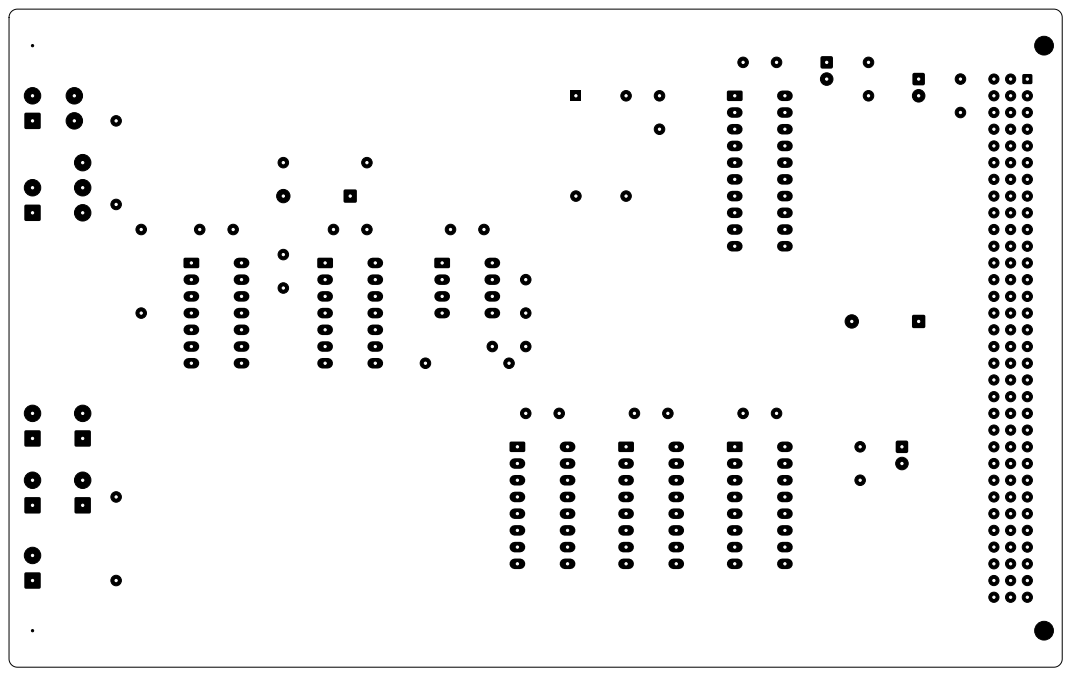
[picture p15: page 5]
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

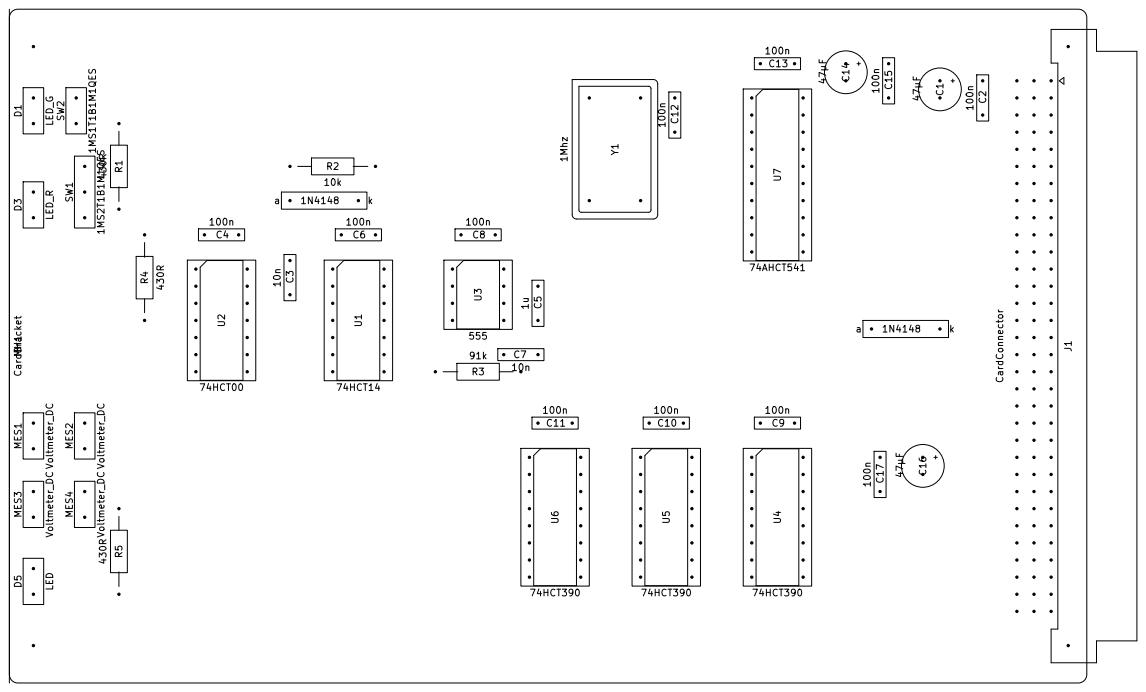
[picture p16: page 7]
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

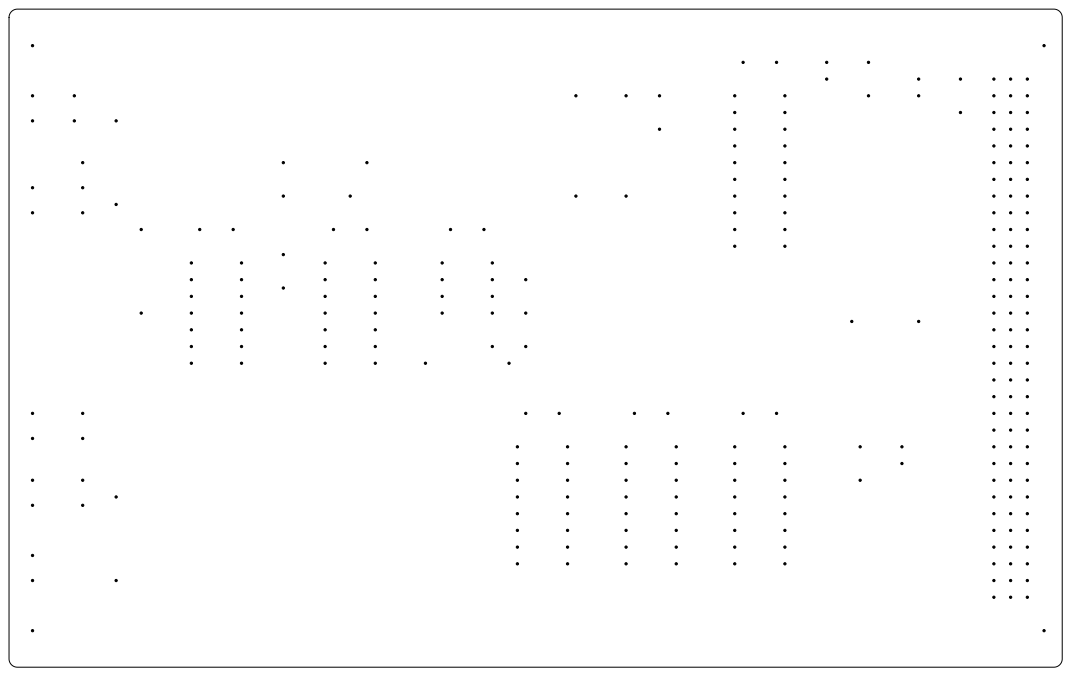
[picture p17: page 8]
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

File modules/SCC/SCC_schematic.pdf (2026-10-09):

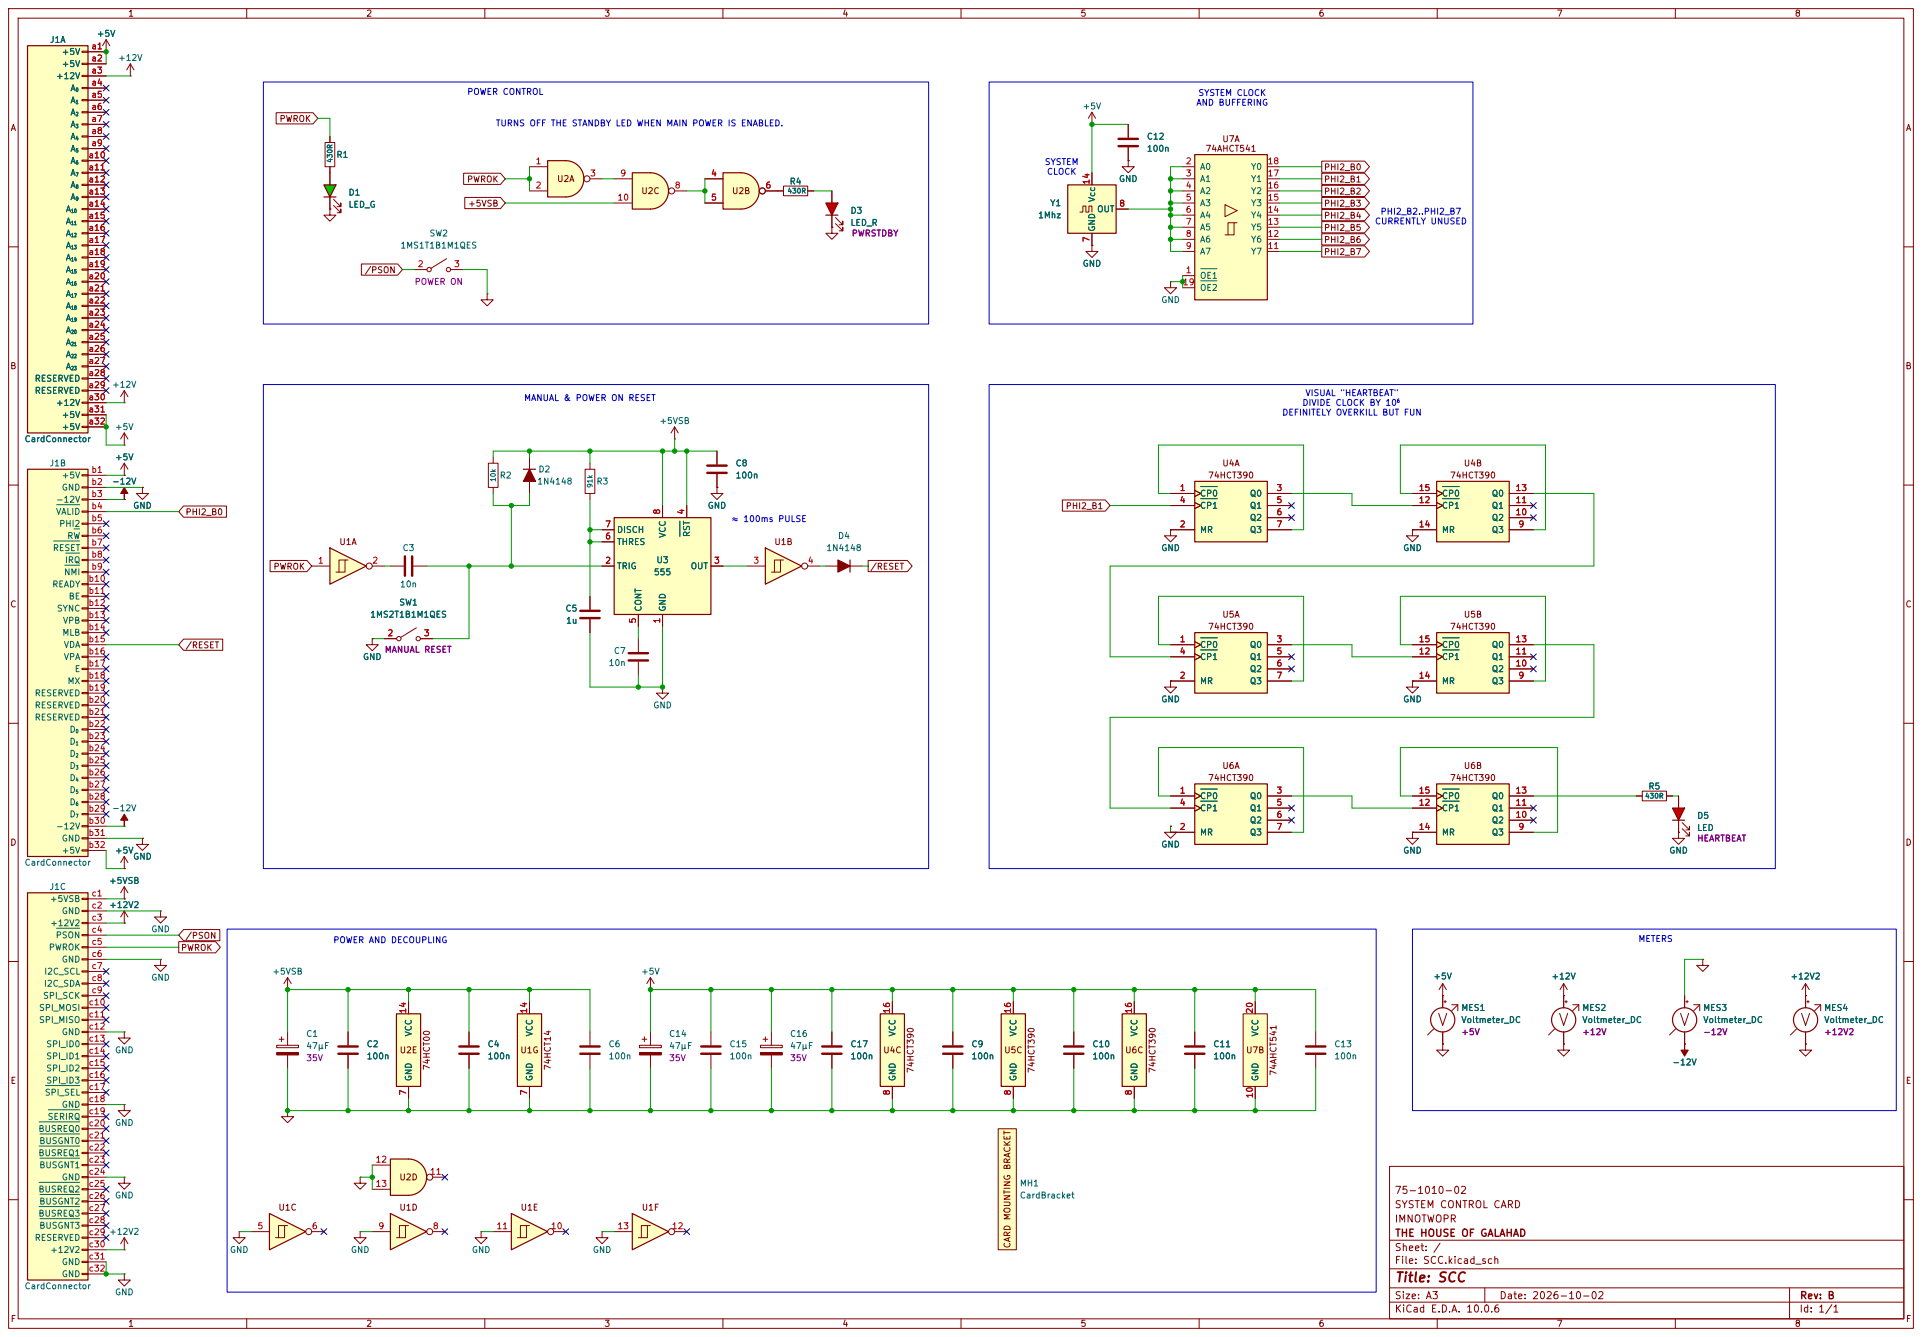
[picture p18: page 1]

TURNS OFF THE STANDBY LED WHEN MAIN POWER IS ENABLED.

Size: A3 | Rev: B | F Date: 2026-10-02
KiCad E.D.A. 10.0.6 | Id: 1/1

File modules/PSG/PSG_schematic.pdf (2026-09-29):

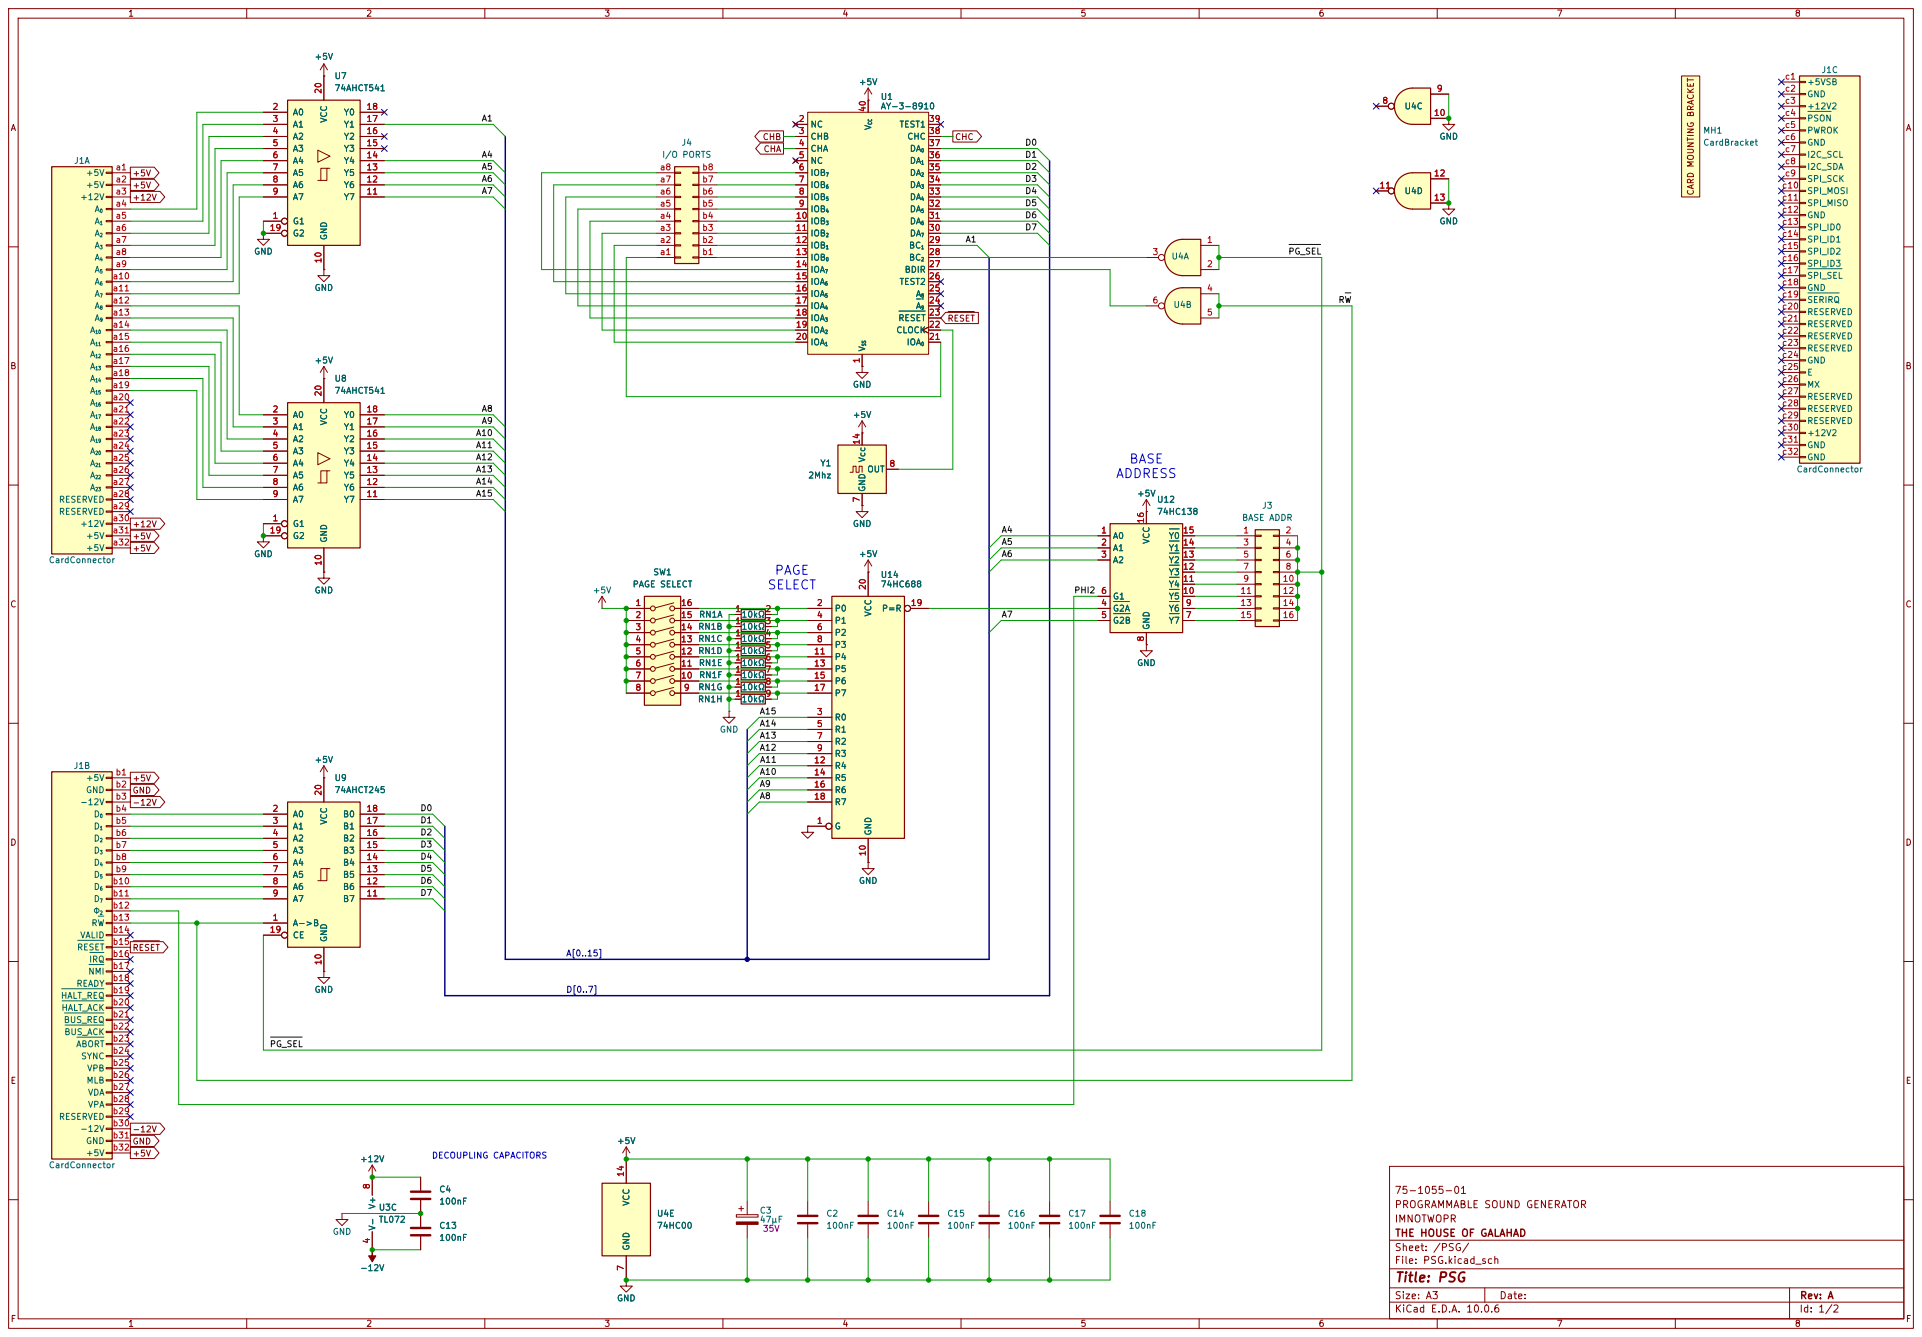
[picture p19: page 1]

a5 | b5 | IOB4 9
a4 | b4 | IOB3 10
a3 | b3 | IOB2 11
a2 | b2 | IOB1 12
a1 | b1 | IOB0 13

IOA6 15
IOA5 16
IOA4 17
IOA3 18
IOA2 19

14 14
13 13
12 12

PROGRAMMABLE SOUND GENERATOR
IMNOTWOPR
THE HOUSE OF GALAHAD
Sheet: /PSG/
File: PSG.kicad_sch
Title: PSG

Size: A3 | Rev: A
KiCad E.D.A. 10.0.6 | Id: 1/2

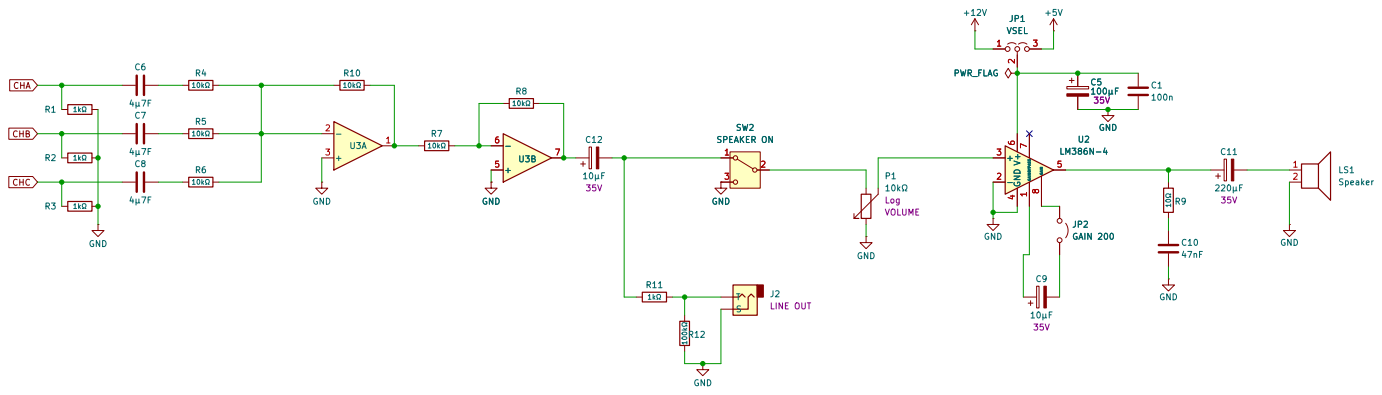
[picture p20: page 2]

PROGRAMMABLE SOUND GENERATOR
IMNOTWOPR
THE HOUSE OF GALAHAD
Sheet: /MIXER/
File: mixer.kicad_sch
Title: PSG

Size: A3 | Rev: A | F Date:
KiCad E.D.A. 10.0.6 | Id: 2/2

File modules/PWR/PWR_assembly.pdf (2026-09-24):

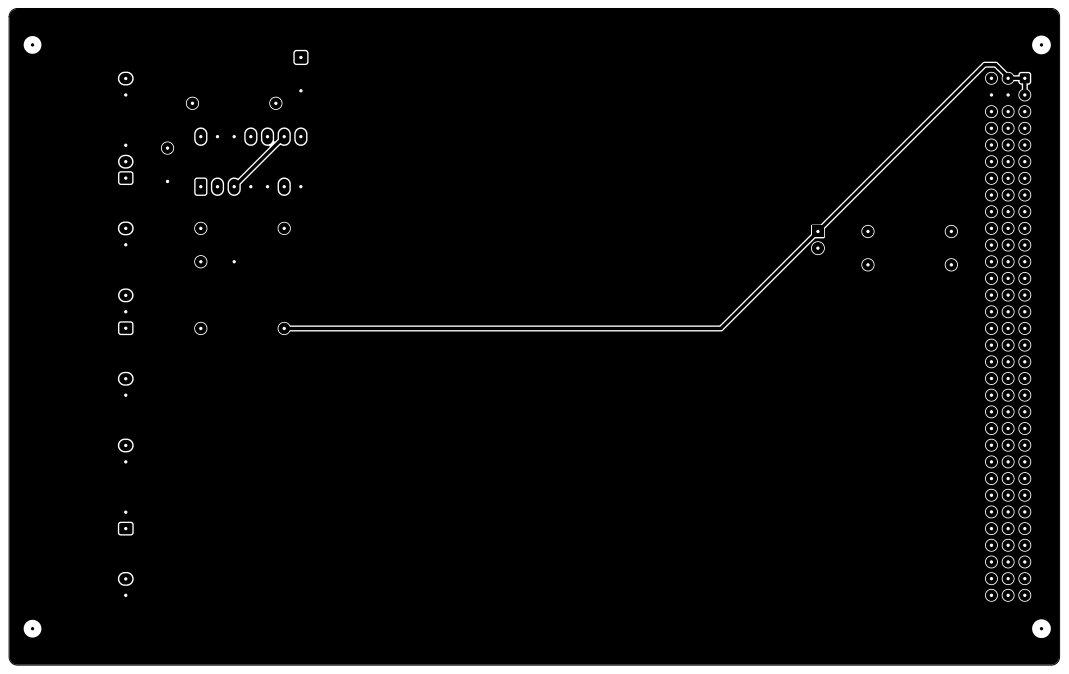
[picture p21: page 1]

DO NOT FOLD, SPINDLE OR MUTILATE
POWER CONTROL
IMNOTWOPR
THE HOUSE OF GALAHAD
Sheet:
File: PWR.kicad_pcb
Title: PWR

Size: A4 | Rev: A
KiCad E.D.A. 10.0.5 | Id: 1/8

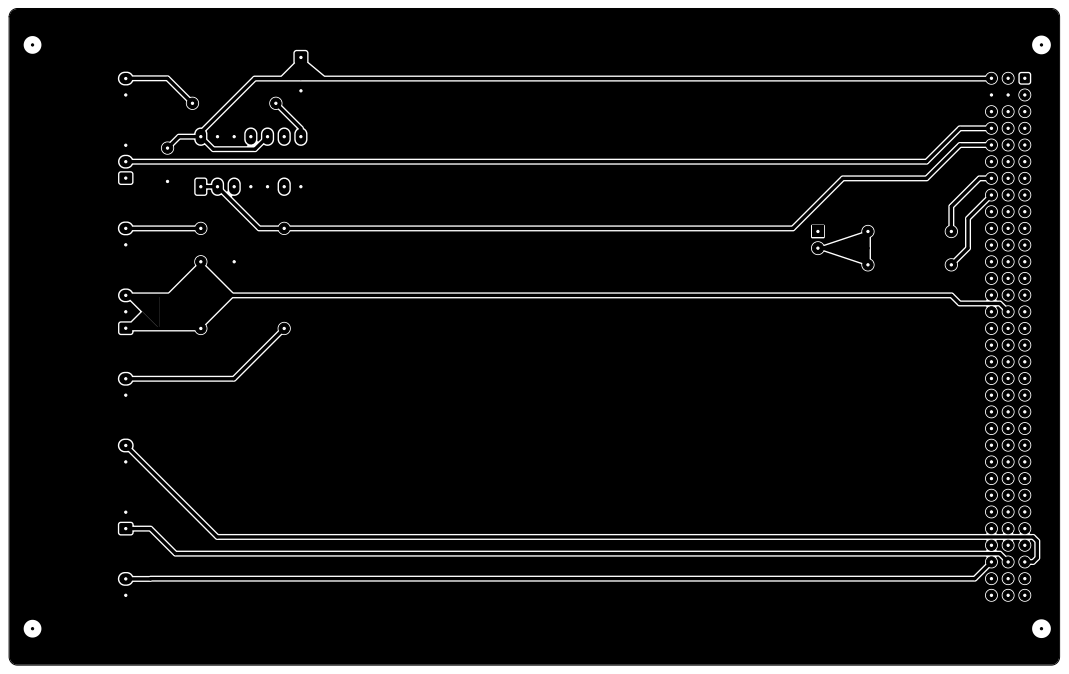
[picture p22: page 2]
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


75-1010-01 PWR OK PWR ON

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

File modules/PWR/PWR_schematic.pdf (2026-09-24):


TURNS OFF THE STANDBY LED WHEN MAIN POWER IS ENABLED. | 3 U1A 74HCT00

7 VCC 14 +5VSB MES4 +12V2 METER +12V2 MES3 -12V METER -12V MES2 +12V METER MES1 +5V METER +5V +12V

Size: A4 | Rev: A
KiCad E.D.A. 10.0.5 | Id: 1/2


POWER CONTROL
IMNOTWOPR
THE HOUSE OF GALAHAD
Sheet: /SYSTEM/
File: system.kicad_sch
Title: PWR

Size: A4 | Rev: A
KiCad E.D.A. 10.0.5 | Id: 2/2

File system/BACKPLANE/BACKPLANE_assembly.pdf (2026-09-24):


DO NOT FOLD, SPINDLE OR MUTILATE
SYSTEM BUS
IMNOTWOPR
THE HOUSE OF GALAHAD
Sheet:
File: BACKPLANE.kicad_pcb
Title: BACKPLANE

Size: A2 | Rev: A
KiCad E.D.A. 10.0.5 | Id: 1/8


DO NOT FOLD, SPINDLE OR MUTILATE


THE HOUSE OF GALAHAD - 75-1005-01 - IMNOTWOPR - BACKPLANE - SYSTEM BUS - REVISION A 2026-09-24

DO NOT FOLD, SPINDLE OR MUTILATE


DO NOT FOLD, SPINDLE OR MUTILATE


DO NOT FOLD, SPINDLE OR MUTILATE

DO NOT FOLD, SPINDLE OR MUTILATE


DO NOT FOLD, SPINDLE OR MUTILATE


DO NOT FOLD, SPINDLE OR MUTILATE

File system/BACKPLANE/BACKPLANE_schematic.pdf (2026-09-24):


Size: A2 | Rev: A
KiCad E.D.A. 10.0.5 | Id: 1/1

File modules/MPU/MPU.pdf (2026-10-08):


/RESET
/IRQ
/NMI READY BE SYNC

Size: A3 | Rev: A
KiCad E.D.A. 10.0.5 | Id: 1/1

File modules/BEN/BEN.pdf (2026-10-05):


DEVELOPMENT CARD
IMNOTWOPR
THE HOUSE OF GALAHAD
Sheet: /
File: BEN.kicad_sch
Title: BEN

Size: A2 | Rev: A
KiCad E.D.A. 10.0.6 | Id: 1/1

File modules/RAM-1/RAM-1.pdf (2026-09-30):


1K RAM
IMNOTWOPR
THE HOUSE OF GALAHAD
Sheet: /RAM-1/
File: RAM-1.kicad_sch
Title: RAM-1

Size: A3 | Rev: A
KiCad E.D.A. 10.0.6 | Id: 1/2


7 VCC 14 U13E 74HCT00 CARD MOUNTING BRACKET MH1 CardBracket

1K RAM
IMNOTWOPR
THE HOUSE OF GALAHAD
Sheet: /SYSTEM/
File: system.kicad_sch
Title: RAM-1

Size: A2 | Rev: A
KiCad E.D.A. 10.0.6 | Id: 2/2

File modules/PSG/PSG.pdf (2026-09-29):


+5V G1 1 VCC 20 U7 Y7 74AHCT541 G1 1 | 11 Y6 12 Y5 13 Y4 14 Y3 15 Y2 16 Y1 17 Y0 18 G2 19

a5 | b5 | IOB4 9
a4 | b4 | IOB3 10
a3 | b3 | IOB2 11
a2 | b2 | IOB1 12

IOA6 15
IOA5 16
IOA4 17
IOA3 18
IOA2 19

PROGRAMMABLE SOUND GENERATOR
IMNOTWOPR
THE HOUSE OF GALAHAD
Sheet: /PSG/
File: PSG.kicad_sch
Title: PSG

Size: A3 | Rev: A
KiCad E.D.A. 10.0.6 | Id: 1/2


PROGRAMMABLE SOUND GENERATOR
IMNOTWOPR
THE HOUSE OF GALAHAD
Sheet: /MIXER/
File: mixer.kicad_sch
Title: PSG

Size: A3 | Rev: A | F Date:
KiCad E.D.A. 10.0.6 | Id: 2/2

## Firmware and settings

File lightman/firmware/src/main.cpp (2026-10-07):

/**
 * @file main.cpp
 * @brief Firmware startup, foreground event loop and local F12 setup menu.
 *
 * Coordinates the terminal, keyboard, serial transport, video and persistent settings.
 */

#include "hardware.h"
#include "hardware/clocks.h"
#include "keyboard.h"
#include "pico/stdlib.h"
#include <algorithm>
#include <cstdio>

using namespace lightman;

namespace
{

Terminal terminal([](void *, std::string_view s) { serial_write(s); }), menu;
Keyboard keyboard;
Config config, draft;
bool in_setup = false;
int selected = 0;
const char *status = "";

/**
 * @brief Rebuild the local setup screen from draft settings and live diagnostics.
 * @note Leaves the host terminal screen unchanged; core 0 later publishes the menu.
 */
void draw_menu()
{
    menu.reset();
    menu.feed("\033[?25l\033[2;4H\033[1mLIGHTMAN SETUP\033[0m");
    
    const char *flow[] = {"None (TX/RX only)", "XON/XOFF", "RTS/CTS (wire handshake pins)"};
    const char *parity[] = {"None", "Even", "Odd"};

    char lines[11][70];
    std::snprintf(lines[0], 70, "Baud rate       %lu", static_cast<unsigned long>(draft.baud));
    std::snprintf(lines[1], 70, "Data bits       %u", draft.data_bits);
    std::snprintf(lines[2], 70, "Parity          %s", parity[draft.parity]);
    std::snprintf(lines[3], 70, "Stop bits       %u", draft.stop_bits);
    std::snprintf(lines[4], 70, "Flow control    %s", flow[static_cast<unsigned>(draft.flow)]);
    std::snprintf(lines[5], 70, "Terminal        %s", draft.vt52 ? "VT52" : "VT100");
    std::snprintf(lines[6], 70, "Local echo      %s", draft.echo ? "On" : "Off");
    std::snprintf(lines[7], 70, "Backspace sends %s", draft.backspace_del ? "DEL (127)" : "BS (8)");
    std::snprintf(lines[8], 70, "Font            %s", draft.font ? "Bold" : "Regular");
    std::snprintf(lines[9], 70, "Normal color    %s", normal_colors[draft.color].name);
    std::snprintf(lines[10], 70, "Restore factory defaults");

    for (int i = 0; i < 11; ++i)
    {
        char pos[24];
        std::snprintf(pos, sizeof pos, "\033[%d;4H", i + 4);
        menu.feed(pos);
        if (i == selected)
            menu.feed("\033[7m");
        menu.feed(lines[i]);
        menu.feed("\033[0m");
    }

    menu.feed("\033[16;4HUp/Down: select   Left/Right/Space: change");
    menu.feed("\033[17;4HEnter: apply   S: apply and save   Esc/F12: cancel");
    menu.feed("\033[19;4HPause host output before changing serial settings or saving.");
    menu.feed("\033[20;4HSaving briefly blanks VGA. Mode changes clear terminal text.");

    char counters[100];
    std::snprintf(counters, sizeof counters, "\033[22;4HRX errors:%lu  TX drops:%lu  PS/2 drops:%lu  VGA late:%lu",
                  (unsigned long)serial_rx_errors(), (unsigned long)serial_tx_drops(), (unsigned long)ps2_overflows(),
                  (unsigned long)video_underruns());
    menu.feed(counters);
    menu.feed("\033[23;4H");
    menu.feed(status);
    menu.feed("\033[24;4H");
    menu.feed(serial_dsr() ? "DSR: asserted" : "DSR: inactive");
    menu.feed(serial_dcd() ? "  DCD: asserted" : "  DCD: inactive");
    menu.feed(serial_ri() ? "  RI: asserted" : "  RI: inactive");
}

/**
 * @brief Cycle the selected draft option or restore draft factory defaults.
 * @param direction Use -1 for the previous choice or +1 for the next.
 * @note Does not apply settings to hardware or write flash.
 */
void change(int direction)
{
    auto cycle = [direction](uint8_t &value, int count) { value = (value + count + direction) % count; };
    switch (selected)
    {
    case 0: {
        auto i = std::find(baud_rates.begin(), baud_rates.end(), draft.baud) - baud_rates.begin();
        draft.baud = baud_rates[(i + baud_rates.size() + direction) % baud_rates.size()];
        break;
    }
    case 1:
        draft.data_bits = draft.data_bits == 8 ? 7 : 8;
        break;
    case 2:
        cycle(draft.parity, 3);
        break;
    case 3:
        draft.stop_bits = draft.stop_bits == 1 ? 2 : 1;
        break;
    case 4:
        draft.flow = static_cast<Flow>((int(draft.flow) + 3 + direction) % 3);
        break;
    case 5:
        draft.vt52 ^= 1;
        break;
    case 6:
        draft.echo ^= 1;
        break;
    case 7:
        draft.backspace_del ^= 1;
        break;
    case 8:
        cycle(draft.font, 2);
        break;
    case 9:
        cycle(draft.color, normal_colors.size());
        break;
    case 10:
        draft = Config{};
        break;
    }
}

/**
 * @brief Close setup, clear its status text and release the peer-pause request.
 */
void close_menu()
{
    in_setup = false;
    status = "";
    serial_hold(false);
}

/**
 * @brief Service serial RX/TX while waiting up to 1.5 seconds for TX to drain.
 * @return True once both the TX queue and UART are idle; false on timeout.
 * @note Incoming bytes continue updating the terminal during this foreground wait.
 */
bool drain_transmitter()
{
    uint32_t start = time_us_32();
    do
    {
        for (int i = 0; i < 4096; ++i)
        {
            int c = serial_read();
            if (c < 0)
                break;
            terminal.feed(static_cast<uint8_t>(c));
        }
        serial_poll();
        if (serial_idle())
            return true;
        sleep_ms(1);
    } while (time_us_32() - start < 1500000);
    return false;
}

/**
 * @brief Handle setup navigation, cancellation, application and optional persistence.
 * @param e Decoded local key press.
 * @note Reports flow-control or flash failures in the menu and keeps setup open.
 */
void setup_key(KeyEvent e)
{
    if (e.key == Key::Escape || e.key == Key::Setup)
    {
        close_menu();
        return;
    }
    if (e.key == Key::Up)
        selected = (selected + 10) % 11;
    if (e.key == Key::Down)
        selected = (selected + 1) % 11;
    if (e.key == Key::Left)
        change(-1);
    if (e.key == Key::Right || (e.key == Key::Character && e.character == ' '))
        change(1);
    bool save = e.key == Key::Character && (e.character == 's' || e.character == 'S');
    if (e.key == Key::Enter || save)
    {
        // Release old software flow control before changing baud/framing/mode.
        serial_hold(false);
        if (!drain_transmitter())
        {
            serial_hold(true);
            status = "TX blocked: restore host CTS/XON, then retry.";
            return;
        }
        if (save)
        {
            serial_hold(true);
            serial_poll();
            // Wait for XOFF to leave even at 300 baud, then allow host reaction.
            if (!drain_transmitter())
            {
                status = "TX blocked; settings have not been saved.";
                return;
            }
            sleep_ms(100);
            if (!settings_save(draft))
            {
                status = "Flash verification failed; changes not applied.";
                return;
            }
            serial_hold(false);
            serial_poll();
            if (!drain_transmitter())
            {
                status = "Saved; TX busy. Retry apply or reboot.";
                return;
            }
        }
        if (!serial_apply(draft))
        {
            serial_hold(true);
            status = "TX still busy; retry.";
            return;
        }
        if (config.vt52 != draft.vt52)
            terminal.reset(draft.vt52);
        config = draft;
        close_menu();
    }
}
} // namespace

/**
 * @brief Initialize the Pico and run the terminal, keyboard and setup event loop.
 * @note Runs on core 0 and does not return; video_start() launches scanout on core 1.
 */
int main()
{
    set_sys_clock_khz(126000, true);
    config = settings_load();
    terminal.reset(config.vt52);
    serial_start(config);
    ps2_start();
    video_start();
    gpio_init(PICO_DEFAULT_LED_PIN);
    gpio_set_dir(PICO_DEFAULT_LED_PIN, GPIO_OUT);
    terminal.feed("Lightman 0.1 - F12 opens setup\r\n");
    uint32_t last_frame = 0, last_ps2_drops = 0, last_bells = 0, bell_at = 0;
    bool bell_on = false;

    while (true)
    {
        serial_poll();

        // Continue receiving into the terminal while the separate setup screen is
        // shown.
        for (int i = 0; i < 256; ++i)
        {
            int c = serial_read();
            if (c < 0)
                break;
            terminal.feed(static_cast<uint8_t>(c));
        }

        auto drops = ps2_overflows();
        if (drops != last_ps2_drops)
        {
            keyboard.reset();
            last_ps2_drops = drops;
        }

        for (int i = 0; i < 32; ++i)
        {
            int c = ps2_read();
            if (c < 0)
                break;
            auto e = keyboard.feed(c);
            if (e.key == Key::None)
                continue;
            if (in_setup)
                setup_key(e);
            else if (e.key == Key::Setup)
            {
                in_setup = true;
                draft = config;
                selected = 0;
                status = "";
                serial_hold(true);
            }
            else if (!terminal.keyboard_locked())
            {
                auto text = encode_key(e, terminal, config.backspace_del);
                serial_write(text);
                if (config.echo)
                    terminal.feed(text);
            }
        }

        uint32_t now = time_us_32();
        if (terminal.bells != last_bells)
        {
            last_bells = terminal.bells;
            bell_at = now;
            bell_on = true;
        }        
        if (bell_on && now - bell_at >= 150000)
            bell_on = false;

        gpio_put(PICO_DEFAULT_LED_PIN, bell_on);

        if (now - last_frame >= 16667)
        {
            last_frame = now;
            if (in_setup)
            {
                draw_menu();
                video_publish(menu, draft);
            }
            else
                video_publish(terminal, config);
        }
        tight_loop_contents();
    }
}

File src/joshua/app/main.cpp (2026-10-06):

#include "joshua/config.hpp"
#include "joshua/instruction.hpp"
#include "joshua/monitor.hpp"
#include "terminal.hpp"
#include <algorithm>
#include <chrono>
#include <csignal>
#include <fstream>
#include <iostream>
#include <thread>
#ifdef _WIN32
#include <fcntl.h>
#include <io.h>
#endif

namespace
{
volatile std::sig_atomic_t interrupted = 0;
void signalHandler(int)
{
    interrupted = 1;
}

void drain(joshua::Machine &machine)
{
    if (machine.acia)
    {
        bool wrote = false;
        while (auto value = machine.acia->takeTransmitted())
        {
            machine.consoleOutput.write(std::cout, *value);
            wrote = true;
        }
        if (wrote)
            std::cout.flush();
    }
}
void run(joshua::Machine &machine, const joshua::Config &config, std::optional<joshua::Word> &lastBreakpoint,
         bool consoleInput)
{
    using Clock = std::chrono::steady_clock;
    auto startTime = Clock::now();
    auto startCycle = machine.bus.cycles();
    std::optional<Terminal> terminal;
    if (consoleInput)
        terminal.emplace();
    std::cerr << "Running; console escape=$" << joshua::hex(config.escape, 2) << ".\n";
    if (machine.acia)
        std::cerr << "Console serial: " << machine.acia->peerSettings().description() << '\n';
    bool bypass = lastBreakpoint && *lastBreakpoint == machine.cpu.r.pc;
    lastBreakpoint.reset();
    std::uint64_t nextPoll = 0;
    while (!interrupted)
    {
        auto elapsed = machine.bus.cycles() - startCycle;
        if (machine.cpu.stopped())
        {
            std::cerr << "\nCPU stopped (STP).\n";
            break;
        }
        if (config.cycleLimit && elapsed >= config.cycleLimit)
        {
            std::cerr << "\nCycle limit reached.\n";
            break;
        }
        if (!bypass)
        {
            auto point = machine.breakpoints.find(machine.cpu.r.pc);
            if (point != machine.breakpoints.end() && point->second)
            {
                lastBreakpoint = point->first;
                std::cerr << "\nBreakpoint at $" << joshua::hex(point->first) << ".\n";
                break;
            }
        }
        bypass = false;
        if (elapsed >= nextPoll)
        {
            nextPoll = elapsed + 256;
            if (terminal)
            {
                bool escaped = false;
                // Bound each poll so pasted text cannot starve emulated time.
                for (unsigned i = 0; i < 64; ++i)
                {
                    auto value = terminal->poll();
                    if (!value)
                        break;
                    if (*value == config.escape)
                    {
                        escaped = true;
                        break;
                    }
                    if (machine.acia)
                        machine.acia->receive(*value);
                }
                if (escaped || terminal->eof())
                {
                    std::cerr << "\nMonitor.\n";
                    break;
                }
            }
            drain(machine);
            if (config.throttle)
            {
                auto target = startTime + std::chrono::nanoseconds(elapsed * 1'000'000'000ull / config.clockHz);
                // Short sleeps keep host input responsive even at low emulated clock
                // rates.
                while (Clock::now() < target && !interrupted)
                {
                    auto remaining = target - Clock::now();
                    std::this_thread::sleep_for(std::min(
                        remaining, std::chrono::duration_cast<Clock::duration>(std::chrono::milliseconds(10))));
                    if (terminal)
                    {
                        auto value = terminal->poll();
                        if (value && *value == config.escape)
                        {
                            drain(machine);
                            return;
                        }
                        if (value && machine.acia)
                            machine.acia->receive(*value);
                    }
                }
            }
        }
        machine.cpu.step();
    }
    drain(machine);
}
} // namespace
int main(int argc, char **argv)
{
    try
    {
        auto config = joshua::parseArguments(argc, argv);
        if (config.help)
        {
            std::cout << joshua::usage();
            return 0;
        }
        if (config.version)
        {
            std::cout << "joshua 0.1.0\n";
            return 0;
        }
#ifdef _WIN32
        // Preserve guest bytes when stdout is redirected to a binary capture.
        _setmode(_fileno(stdout), _O_BINARY);
#endif
        std::signal(SIGINT, signalHandler);
        std::signal(SIGTERM, signalHandler);
        joshua::Machine machine(config);
        joshua::Monitor monitor(machine, std::cerr);
        std::ifstream script;
        std::istream *commands = &std::cin;
        if (!config.script.empty())
        {
            script.open(config.script);
            if (!script)
                throw std::runtime_error("cannot open monitor script: " + config.script.string());
            commands = &script;
        }
        std::optional<joshua::Word> lastBreakpoint;
        std::cerr << "joshua 0.1.0 - type help for monitor commands.\n";
        if (config.run)
            run(machine, config, lastBreakpoint, config.script.empty());
        bool failed = false;
        while (!interrupted)
        {
            drain(machine);
            if (commands == &std::cin)
                std::cerr << machine.status() << "\njoshua> " << std::flush;
            std::string line;
            if (!std::getline(*commands, line))
                break;
            try
            {
                auto action = monitor.execute(line);
                if (action == joshua::MonitorAction::quit)
                    break;
                if (action == joshua::MonitorAction::run)
                    run(machine, config, lastBreakpoint, config.script.empty());
            }
            catch (const std::exception &error)
            {
                std::cerr << "Error: " << error.what() << '\n';
                failed = true;
                if (commands == &script)
                    break;
            }
        }
        drain(machine);
        return failed ? 1 : 0;
    }
    catch (const std::exception &error)
    {
        std::cerr << "joshua: " << error.what() << '\n';
        return 1;
    }
}

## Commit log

2026-09-18 initial re-commit
    [CASE-8.FCStd, CASE-8.step]
2026-09-18 project reinit, backplane
    [BACKPLANE.kicad_pcb, BACKPLANE.kicad_sch, MPU-65.kicad_pcb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]
2026-09-20 backplane & power control
    [BACKPLANE.kicad_pcb, BACKPLANE.kicad_sch, CASE-8.FCStd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]
2026-09-20 removed freerouting.dsn
    [freerouting.dsn]
2026-09-21 added joshua
    [MPU-65X.kicad_pcb, MPU-65X.kicad_sch, PWR-CTRL.kicad_pcb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]
2026-09-21 updated ferris makefile to use ca65
    [config.cfg]
2026-09-21 mpu-65x circuit & pcb
    [MPU-65X.kicad_pcb, MPU-65X.kicad_sch, system.kicad_sch]
2026-09-22 Formatting and MPU-65X work
    [MPU-65X.kicad_pcb, MPU-65X.kicad_sch, system.kicad_sch]
2026-09-22 Added serial I/O (SPI/I2C) support for system bus. Updated documentation.
2026-09-22 added i2c pullups to pwr-ctrl
    [PWR-CTRL.kicad_pcb, PWR-CTRL.kicad_sch, system.kicad_sch]
2026-09-22 added i2c pullsups to backplane
    [BACKPLANE.kicad_pcb, BACKPLANE.kicad_sch]
2026-09-22 added bus line analyzer
    [BLA-65.kicad_pcb, BLA-65.kicad_sch, MSD-65.kicad_pcb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]
2026-09-23 bla panel
    [BLA-65.kicad_pcb]
2026-09-23 backplane updates and notes
    [BACKPLANE.kicad_pcb, BACKPLANE.kicad_sch]
2026-09-24 pwr panel & associated readmes
    [BACKPLANE.kicad_pcb, PWR-CTRL.kicad_pcb, PWR.kicad_pcb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]
2026-09-24 pwr pcb
    [PWR.kicad_pcb, PWR.kicad_sch, system.kicad_sch]
2026-09-24 backplane pcb
    [BACKPLANE.kicad_pcb, BACKPLANE.kicad_sch]
2026-09-24 minor PW PCB tweaks
    [BLA.kicad_pcb, BLA.kicad_sch, MPU-65X.kicad_pcb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]
2026-09-24 Add top 3D render image to README
    Added 3D render image for the top view of the PCB.
2026-09-24 version 1 of pwr module, power panel, & backplane pcb
    [BACKPLANE.kicad_pcb, BACKPLANE.kicad_sch, PWR.kicad_pcb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]
2026-09-24 bla pcb and schematic
    [BACKPLANE.kicad_pcb, BLA.kicad_pcb, BLA.kicad_sch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]
2026-09-25 project cleanup
    [BLA.kicad_pcb, MPX.kicad_pcb, MPX.kicad_sch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]
2026-09-25 work on mpx module
    [MPX.kicad_pcb, MPX.kicad_sch, TEMPLATE.kicad_pcb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]
2026-09-26 cleanup and mpx work
    [MPX.kicad_pcb, MPX.kicad_sch, system.kicad_sch]
2026-09-27 cleanup; added ext board
    [BLA.kicad_pcb, CTL.kicad_pcb, CTL.kicad_sch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]
2026-09-27 mega updates. psg module. ferrous & example makefiles overhaul
    [PSG.kicad_pcb, PSG.kicad_sch, PWR.kicad_pcb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]
2026-09-29 initial RAM-1
    [RAM-1.kicad_pcb, RAM-1.kicad_sch, ROM.kicad_pcb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]
2026-09-30 1k RAM work
    [RAM-1.kicad_pcb, RAM-1.kicad_sch, system.kicad_sch]
2026-09-30 restructure template; stub for vdc & mpu
    [MPU.kicad_sch, TEMPLATE.kicad_pcb, TEMPLATE.kicad_sch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]
2026-10-01 mpu wip
    [MPU.kicad_pcb, MPU.kicad_sch, VDC.kicad_pcb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]
2026-10-01 added new footprints for lcds. started ben circuit
    [BEN.kicad_pcb, BEN.kicad_sch]
2026-10-02 ben schematic wip
    [BEN.kicad_pcb, BEN.kicad_sch]
2026-10-02 lib work and ben wip
    [BEN.kicad_pcb, BEN.kicad_sch, BTC.kicad_pcb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]
2026-10-05 ben schematic
    [BEN.kicad_pcb, BEN.kicad_sch, TEMPLATE_8HP.kicad_pcb]
2026-10-05 ben work; fixed logic issue with pwr; started lightman
    [BEN.kicad_pcb, BEN.kicad_sch, PWR.kicad_sch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]
2026-10-06 lightman source
    [lightman.kicad_pcb, lightman.kicad_sch]
2026-10-06 lightman pcb
    [PWR.kicad_pcb, PWR.kicad_sch, lightman.kicad_pcb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]
2026-10-07 numerous updates; documentation, ferruous, lightman, etc.
    [CRT.kicad_pcb, CRT.kicad_sch, MPU.kicad_sch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]
2026-10-08 tracework for lightman
    [lightman.kicad_pcb, lightman.kicad_sch]
2026-10-08 migrated PWR to SCC; updates to MPU, more work pending
    [MPU.kicad_sch, SCC.kicad_pcb, SCC.kicad_sch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]
2026-10-09 SCC module revision B
    [SCC.kicad_pcb, SCC.kicad_sch, bom.csv]
2026-10-09 work on ser-2 board. library cleanup
    [SER-2.kicad_pcb, SER-2.kicad_sch, system.kicad_sch]
2026-10-12 par board & schematic wip
2026-10-13 added monitor and clk pcb
2026-10-13 fixed level shifter footprint width
2026-10-14 pxx prototype card
2026-10-14 Revise PXX PCB README with additional information
    Updated the README to include additional details about the PXX PCB and its features.
2026-10-16 lightman pcb gerbers
2026-10-16 Add BOM notes to README
    Added BOM notes for level shifters and their sourcing.
2026-10-16 added support for VT100 L1-L4 hardware LEDs
2026-10-16 added host controlled LEDs to lightman
2026-10-25 added 9V power supply
2026-10-28 ram pcb update
2026-10-29 track work for ram
2026-11-02 Format README.md for CLX PCB module
2026-11-11 modified cartridge expander from 64 to 22 edge connector
2026-11-11 readded #OE to cartridge connector
2026-11-11 work on crt pcb
2026-11-13 added initial i2c support for kernal
